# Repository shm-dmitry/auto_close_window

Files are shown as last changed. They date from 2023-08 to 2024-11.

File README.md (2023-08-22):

This project allows auto-open and auto-close your windows.
Project consists schematics of 3 modules and firmware for 2 controllers

Project re-started

In-door modules:
==============

1. Placed on window neare handle. It controls handle state (via hall sensor and magnet) and allows to you to push button open or close manually
Also this module connected to WIFI and allows to to control your window from any smart house server (via MQTT protocol).
2. Placed on up-side window frame. Contains servo, receives commands from module#1 and executes it.

Out-door module:
==============

1. Listen for a noise and check air quality. 

Project status
==============

| Hardware | status |
| ---- | ---- |
| Indoor schema :: near-handle module | no |
| Indoor schema :: servo module | no |
| Indoor schema :: digital channel to outdoor schema | no |
| Outdoor module schema :: microcontroller and its periphery | no |
| Outdoor module schema :: sensors | no |

| Board | status |
| ---- | ---- |
| Indoor board :: near-handle module | no |
| Indoor board :: servo module | no |
| Outdoor module board | no |

| Firmware | status |
| ---- | ---- |
| Indoor firmware :: hardware sensors - hall, switch and soft lock | no |
| Indoor firmware :: buttons | no |
| Indoor firmware :: servo control and calibration | no |
| Indoor firmware :: led indication | no |
| Indoor firmware :: controller | no |
| Outdoor firmware :: BMP280 | no |
| Outdoor firmware :: SGP30 | no |
| Outdoor firmware :: Noise sensor | no |
| Outdoor firmware :: Sensor value filters and controller | no |
| Outdoor firmware :: Data transmitter | no |

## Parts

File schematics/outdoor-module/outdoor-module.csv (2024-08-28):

Source: | /opt/work-iot/auto_close_window/schematics/outdoor-module/outdoor-module.kicad_sch
Date: | 2024-08-24T21:54:59+0300
Tool: | Eeschema 8.0.4-8.0.4-0~ubuntu22.04.1
Generator: | /usr/share/kicad/plugins/bom_csv_grouped_by_value_with_fp.py
Component Count: | 124
Ref | Qnty | Value | Cmp name | Footprint | Description | Vendor | DNP
C1, C2, C4, C9, C11, C16, C17, C24, C25, C27, C28, C29, C31, C33, C37, C38, C39, C40, C41, C42, C45 | 21 | 100 nF | C | Capacitor_SMD:C_0603_1608Metric | Unpolarized capacitor
C3, C7 | 2 | 100 uF | C_Polarized | Capacitor_THT:CP_Radial_D6.3mm_P2.50mm | Polarized capacitor
C5, C6 | 2 | 15 pF | C | Capacitor_SMD:C_0603_1608Metric | Unpolarized capacitor
C8, C13, C14, C20, C34, C35, C44 | 7 | 22 uF | C | Capacitor_SMD:C_1210_3225Metric | Unpolarized capacitor
C10, C15, C18, C19, C30 | 5 | 1 uF | C | Capacitor_SMD:C_0603_1608Metric | Unpolarized capacitor
C12, C26 | 2 | 2.2 uF | C | Capacitor_SMD:C_0603_1608Metric | Unpolarized capacitor
C21 | 1 | 1 nF | C | Capacitor_SMD:C_0603_1608Metric | Unpolarized capacitor
C22, C32 | 2 | 47 nF | C | Capacitor_SMD:C_0603_1608Metric | Unpolarized capacitor
C23 | 1 | 200 pF | C | Capacitor_SMD:C_0603_1608Metric | Unpolarized capacitor
C36 | 1 | 4.7 uF | C | Capacitor_SMD:C_0603_1608Metric | Unpolarized capacitor
D1 | 1 | red/green, common cathode, F3 | LED_Dual_AKA | LED_THT:LED_D5.0mm-3 | Dual LED, common cathode on pin 2
D3, D5 | 2 | 15MQ030NPBF | D | Diode_SMD:D_SMA | Diode
D4 | 1 | BAV21WS | D | Diode_SMD:D_SOD-323F | Diode
D6 | 1 | SMAJ26A | SMAJ26A | Diode_SMD:D_SMA | 400W unidirectional Transient Voltage Suppressor, 26.0Vr, SMA(DO-214AC)
D7 | 1 | ES2J | D | Diode_SMD:D_SMB | Diode
F1, F2 | 2 | 3A | Fuse | Library:FuseHolder1808 | Fuse
H1, H2, H3, H4, H5 | 5 | MountingHole | MountingHole | MountingHole:MountingHole_2.2mm_M2 | Mounting Hole without connection
J1 | 1 | 2*LiFePo4@18650@1800mAh, 6,4V | Conn_01x02_Socket | Connector_PinSocket_2.54mm:PinSocket_1x02_P2.54mm_Vertical | Generic connector, single row, 01x02, script generated
J2 | 1 | USBASP | Conn_02x05_Odd_Even | Connector_PinHeader_2.54mm:PinHeader_2x05_P2.54mm_Vertical | Generic connector, double row, 02x05, odd/even pin numbering scheme (row 1 odd numbers, row 2 even numbers), script generated (kicad-library-utils/schlib/autogen/connector/)
J3 | 1 | Charger | Conn_01x02_Socket | Connector_JST:JST_XH_B2B-XH-A_1x02_P2.50mm_Vertical | Generic connector, single row, 01x02, script generated
L3 | 1 | AMPLF0630, 8,2uH | L | Inductor_SMD:L_Abracon_ASPI-0630LR | Inductor
MK1 | 1 | VSM3729AT-GL9-A30 | MEMS-4PIN | Library:SMD03722C4
Q1, Q2 | 2 | IRLML5203 | IRLML5203 | Package_TO_SOT_SMD:SOT-23 | -3.0A Id, -30V Vds, 98mOhm Rds, P-Channel HEXFET Power MOSFET, SOT-23
Q3, Q4, Q5, Q6, Q7 | 5 | IRLML0030 | IRLML0030 | Package_TO_SOT_SMD:SOT-23 | 5.3A Id, 30V Vds, 27mOhm Rds, N-Channel HEXFET Power MOSFET, SOT-23
R1, R2, R6, R19 | 4 | 10K | R | Resistor_SMD:R_0805_2012Metric | Resistor
R3, R5, R10, R11 | 4 | 4K7 | R | Resistor_SMD:R_0805_2012Metric | Resistor
R4 | 1 | 1K | R | Resistor_SMD:R_0805_2012Metric | Resistor
R7 | 1 | 2 | R | Resistor_SMD:R_0805_2012Metric | Resistor
R8, R23, R25, R26 | 4 | 100K | R | Resistor_SMD:R_0805_2012Metric | Resistor
R9 | 1 | 45K | R | Resistor_SMD:R_0805_2012Metric | Resistor
R12 | 1 | 4R7 | R | Resistor_SMD:R_0805_2012Metric | Resistor
R13, R14, R17 | 3 | 4K | R | Resistor_SMD:R_0805_2012Metric | Resistor
R15 | 1 | 200K | R | Resistor_SMD:R_0805_2012Metric | Resistor
R16, R27 | 2 | 0.01 R | R | Resistor_SMD:R_1206_3216Metric | Resistor
R18, R21, R24, R28, R29, R30 | 6 | 10 | R | Resistor_SMD:R_0805_2012Metric | Resistor
R20 | 1 | 2K2 | R | Resistor_SMD:R_0805_2012Metric | Resistor
RV1, RV3 | 2 | RM065, 100K | R_Potentiometer | Potentiometer_THT:Potentiometer_Runtron_RM-065_Vertical | Potentiometer
RV2 | 1 | JVR-05N180M | Varistor | Varistor:RV_Disc_D7mm_W4.5mm_P5mm | Voltage dependent resistor
TP1 | 1 | CHG SUPPLY | TestPoint | TestPoint:TestPoint_Pad_D1.0mm | test point
TP2 | 1 | GND | TestPoint | Library:TestPoint_Plated_Hole_D1.0mm | test point
TP3 | 1 | 1V8 | TestPoint | TestPoint:TestPoint_Pad_D1.0mm | test point
TP4 | 1 | +5V | TestPoint | TestPoint:TestPoint_Pad_D1.0mm | test point
TP5 | 1 | 3V3 | TestPoint | TestPoint:TestPoint_Pad_D1.0mm | test point
TP6 | 1 | VSYS | TestPoint | TestPoint:TestPoint_Pad_D1.0mm | test point
TP7 | 1 | MK_OUT | TestPoint | TestPoint:TestPoint_Pad_D1.0mm | test point
TP9 | 1 | ACDET | TestPoint | TestPoint:TestPoint_Pad_D1.0mm | test point
TP10 | 1 | NOISE | TestPoint | TestPoint:TestPoint_Pad_D1.0mm | test point
TP11 | 1 | ACDRV | TestPoint | TestPoint:TestPoint_Pad_D1.0mm | test point
TP12 | 1 | ACOK | TestPoint | TestPoint:TestPoint_Pad_D1.0mm | test point
U1 | 1 | ATmega328-A | ATmega328-A | Package_QFP:TQFP-32_7x7mm_P0.8mm | 20MHz, 32kB Flash, 2kB SRAM, 1kB EEPROM, TQFP-32
U2 | 1 | STX882@315MHz | STX882 | Library:STX882_Vertical
U3 | 1 | MCP1703T-5002E | AMS1117-3.3 | Package_TO_SOT_SMD:SOT-23 | 1A Low Dropout regulator, positive, 3.3V fixed output, SOT-223
U4 | 1 | MCP1703T-3302E | AMS1117-3.3 | Package_TO_SOT_SMD:SOT-23 | 1A Low Dropout regulator, positive, 3.3V fixed output, SOT-223
U5 | 1 | MCP1703T-1802E | MCP1703Ax-500xxTT | Package_TO_SOT_SMD:SOT-23 | Low Quiescent Current LDO Regulator, 5.0V, 250mA, Vin<=16V, SOT-23
U6 | 1 | PCA9306 | PCA9306 | Package_SO:MSOP-8_3x3mm_P0.65mm | Dual bidirectional I2C Bus and SMBus voltage level translator
U7 | 1 | BME280 | BME280 | Package_LGA:Bosch_LGA-8_2.5x2.5mm_P0.65mm_ClockwisePinNumbering | 3-in-1 sensor, humidity, pressure, temperature, I2C and SPI interface, 1.71-3.6V, LGA-8
U8 | 1 | BQ24780S | BQ24780S | Package_DFN_QFN:QFN-28-1EP_4x4mm_P0.4mm_EP2.6x2.6mm_ThermalVias
U9, U10 | 2 | AD8541 | AD8211 | Package_TO_SOT_SMD:SOT-23-5 | 65V High Voltage, Current Shunt Monitor, 20V/V gain, bandwidth 500kHz, Vcc=5V, SOT-23-5
U12 | 1 | INA219 | INA219 | Package_SO:SOIC-8_3.9x4.9mm_P1.27mm
X1 | 1 | HC-49U, 8MHz | Crystal | Crystal:Crystal_HC49-U_Vertical | Two pin crystal

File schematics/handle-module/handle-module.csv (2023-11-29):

Source: | /opt/work-iot/auto_close_window/schematics/handle-module/handle-module.kicad_sch
Date: | Пн 27 ноя 2023 12:29:32
Tool: | Eeschema 7.0.9-7.0.9~ubuntu22.04.1
Generator: | /usr/share/kicad/plugins/bom_csv_grouped_by_value_with_fp.py
Component Count: | 117
Ref | Qnty | Value | Cmp name | Footprint | Description | Vendor | DNP
C1, C2, C10, C22 | 4 | 2.2 uF | C | Capacitor_SMD:C_0603_1608Metric | Unpolarized capacitor
C3, C4, C29 | 3 | 10 nF | C | Capacitor_SMD:C_0603_1608Metric | Unpolarized capacitor
C5, C6 | 2 | 100 uF | C_Polarized | Capacitor_THT:CP_Radial_D6.3mm_P2.50mm | Polarized capacitor
C7, C13, C14, C19, C30, C31, C36 | 7 | 22 uF | C | Capacitor_SMD:C_1210_3225Metric | Unpolarized capacitor
C8, C18, C27 | 3 | 1 uF | C | Capacitor_SMD:C_0603_1608Metric | Unpolarized capacitor
C9, C11, C15, C16, C20, C21, C23, C24, C32, C34, C35 | 11 | 100 nF | C | Capacitor_SMD:C_0603_1608Metric | Unpolarized capacitor
C12 | 1 | 1 nF | C | Capacitor_SMD:C_0603_1608Metric | Unpolarized capacitor
C17, C28 | 2 | 47 nF | C | Capacitor_SMD:C_0603_1608Metric | Unpolarized capacitor
C25, C26 | 2 | 15 pF | C | Capacitor_SMD:C_0603_1608Metric | Unpolarized capacitor
C33 | 1 | 10 uF | C | Capacitor_SMD:C_0603_1608Metric | Unpolarized capacitor
D1 | 1 | red/green, common cathode, F3 | LED_Dual_AKA | LED_THT:LED_D5.0mm-3 | Dual LED, common cathode on pin 2
D2, D7, D8 | 3 | 15MQ030NPBF | D | Diode_SMD:D_SMA | Diode
D3, D4, D5, D6 | 4 | BAV21WS | D | Diode_SMD:D_SOD-323F | Diode
D9, D10 | 2 | ES2J | D | Diode_SMD:D_SMB | Diode
F1, F2 | 2 | 3A | Fuse | Library:FuseHolder1808 | Fuse
H1, H2, H3, H4 | 4 | MountingHole | MountingHole | MountingHole:MountingHole_2.2mm_M2 | Mounting Hole without connection
J1 | 1 | 2*LiFePo4@18650@1800mAh, 6,4V | Conn_01x02_Socket | Connector_PinSocket_2.54mm:PinSocket_1x02_P2.54mm_Vertical | Generic connector, single row, 01x02, script generated
J2 | 1 | JST XH B3B | Conn_01x03_Pin |  | Generic connector, single row, 01x03, script generated
J3 | 1 | JST XH B3B | Conn_01x03_Socket | Connector_JST:JST_XH_B3B-XH-A_1x03_P2.50mm_Vertical | Generic connector, single row, 01x03, script generated
J4 | 1 | USBASP | Conn_02x05_Odd_Even | Connector_PinHeader_2.54mm:PinHeader_2x05_P2.54mm_Vertical | Generic connector, double row, 02x05, odd/even pin numbering scheme (row 1 odd numbers, row 2 even numbers), script generated (kicad-library-utils/schlib/autogen/connector/)
JP1 | 1 | AC Detect | SolderJumper_2_Open | Jumper:SolderJumper-2_P1.3mm_Open_TrianglePad1.0x1.5mm | Solder Jumper, 2-pole, open
L1, L2 | 2 | ? | L |  | Inductor
L3 | 1 | AMPLF0630, 8,2uH | L | Inductor_SMD:L_Abracon_ASPI-0630LR | Inductor
Q1, Q2 | 2 | IRLML5203 | IRLML5203 | Package_TO_SOT_SMD:SOT-23 | -3.0A Id, -30V Vds, 98mOhm Rds, P-Channel HEXFET Power MOSFET, SOT-23
Q3, Q4, Q5, Q6, Q7, Q8, Q9, Q10 | 8 | IRLML0030 | IRLML0030 | Package_TO_SOT_SMD:SOT-23 | 5.3A Id, 30V Vds, 27mOhm Rds, N-Channel HEXFET Power MOSFET, SOT-23
R1, R2, R3, R4, R6, R7, R16, R18, R21, R22, R25, R26 | 12 | 10K | R | Resistor_SMD:R_0805_2012Metric | Resistor
R5 | 1 | 1K | R | Resistor_SMD:R_0805_2012Metric | Resistor
R8 | 1 | 2R | R | Resistor_SMD:R_0805_2012Metric | Resistor
R9, R11, R12, R30 | 4 | 100K | R | Resistor_SMD:R_0805_2012Metric | Resistor
R10 | 1 | 45K | R | Resistor_SMD:R_0805_2012Metric | Resistor
R13 | 1 | 4R7 | R | Resistor_SMD:R_0805_2012Metric | Resistor
R14, R15, R19 | 3 | 4K | R | Resistor_SMD:R_0805_2012Metric | Resistor
R17, R28 | 2 | 0.01 R | R | Resistor_SMD:R_1206_3216Metric | Resistor
R20, R23, R27, R29 | 4 | 10 | R | Resistor_SMD:R_0805_2012Metric | Resistor
R24 | 1 | 6R8 | R | Resistor_SMD:R_0805_2012Metric | Resistor
R31 | 1 | 7K | R | Resistor_SMD:R_0805_2012Metric | Resistor
RV1 | 1 | JVR-05N180M | Varistor | Varistor:RV_Disc_D7mm_W4.5mm_P5mm | Voltage dependent resistor
SW1, SW2 | 2 | KLS7-TS3601-5.0-180 | SW_Push | Library:SW_PUSH_P6.5_W3.5 | Push button switch, generic, two pins
TP1 | 1 | VBAT | TestPoint | TestPoint:TestPoint_Pad_D1.0mm | test point
TP2 | 1 | GND | TestPoint | TestPoint:TestPoint_Plated_Hole_D2.0mm | test point
TP3 | 1 | +5V | TestPoint | TestPoint:TestPoint_Pad_D1.0mm | test point
TP4 | 1 | VSYS | TestPoint | TestPoint:TestPoint_Pad_D1.0mm | test point
TP5 | 1 | CHG SUPPLY | TestPoint | TestPoint:TestPoint_Pad_D1.0mm | test point
TP6 | 1 | ILIM | TestPoint | TestPoint:TestPoint_Pad_D1.0mm | test point
U1 | 1 | STX882@443MHz | STX882 | Library:STX882_Vertical
U2 | 1 | SRX882@443MHz | SRX882 | Library:SRX882_Vertical
U3 | 1 | AMS1117-5.0 | AMS1117-5.0 | Package_TO_SOT_SMD:SOT-223-3_TabPin2 | 1A Low Dropout regulator, positive, 5.0V fixed output, SOT-223
U4 | 1 | MCP1703T-3302E | AMS1117-3.3 | Package_TO_SOT_SMD:SOT-23 | 1A Low Dropout regulator, positive, 3.3V fixed output, SOT-223
U5 | 1 | ATmega328-A | ATmega328-A | Package_QFP:TQFP-32_7x7mm_P0.8mm | 20MHz, 32kB Flash, 2kB SRAM, 1kB EEPROM, TQFP-32
U6 | 1 | BQ24780S | BQ24780S | Package_DFN_QFN:QFN-28-1EP_4x4mm_P0.4mm_EP2.6x2.6mm_ThermalVias
X1 | 1 | HC-49U, 8MHz | Crystal | Crystal:Crystal_HC49-U_Vertical | Two pin crystal

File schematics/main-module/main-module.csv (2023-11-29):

Source: | /opt/work-iot/auto_close_window/schematics/main-module/main-module.kicad_sch
Date: | Пн 27 ноя 2023 12:27:09
Tool: | Eeschema 7.0.9-7.0.9~ubuntu22.04.1
Generator: | /usr/share/kicad/plugins/bom_csv_grouped_by_value_with_fp.py
Component Count: | 102
Ref | Qnty | Value | Cmp name | Footprint | Description | Vendor | DNP
C1 | 1 | 2.2 uF | C | Capacitor_SMD:C_0603_1608Metric | Unpolarized capacitor
C2, C9, C10, C11, C12, C19, C27, C28, C30, C32 | 10 | 22 uF | C | Capacitor_SMD:C_1210_3225Metric | Unpolarized capacitor
C3, C5, C6, C21, C33 | 5 | 10 uF | C | Capacitor_SMD:C_0603_1608Metric | Unpolarized capacitor
C4 | 1 | 1000 uF | C_Polarized | Capacitor_THT:CP_Radial_D8.0mm_P3.50mm | Polarized capacitor
C14, C15, C20, C22, C24, C34, C35 | 7 | 100 nF | C | Capacitor_SMD:C_0603_1608Metric | Unpolarized capacitor
C16 | 1 | 1 uF | C | Capacitor_SMD:C_0603_1608Metric | Unpolarized capacitor
C17, C18 | 2 | 100 uF | C_Polarized | Capacitor_THT:CP_Radial_D6.3mm_P2.50mm | Polarized capacitor
C23 | 1 | 1 nF | C | Capacitor_SMD:C_0603_1608Metric | Unpolarized capacitor
C25 | 1 | 500 nF | C | Capacitor_SMD:C_0603_1608Metric | Unpolarized capacitor
C26, C29 | 2 | 0.1 uF | C | Capacitor_SMD:C_0603_1608Metric | Unpolarized capacitor
C31 | 1 | 100 uF | C | Capacitor_SMD:C_0603_1608Metric | Unpolarized capacitor
D1 | 1 | SMAJ5.0CA-TR | ESD9B3.3ST5G | Diode_SMD:D_SMA | ESD protection diode, 3.3Vrwm, SOD-923
D2 | 1 | US1M | D | Diode_SMD:D_SMA | Diode
D4 | 1 | HER508 | D | Diode_THT:D_DO-201AD_P3.81mm_Vertical_AnodeUp | Diode
D5 | 1 | LED | LED | LED_THT:LED_D1.8mm_W3.3mm_H2.4mm | Light emitting diode
D6 | 1 | MB10S | D_Bridge_+-AA | Library:MBS | Diode bridge, +ve/-ve/AC/AC
F1 | 1 | 6A | Fuse | Library:FuseHolder1808 | Fuse
F2 | 1 | 3A | Fuse | Library:FuseHolder1808 | Fuse
H1, H2, H3, H4 | 4 | MountingHole | MountingHole | MountingHole:MountingHole_2.2mm_M2 | Mounting Hole without connection
J1 | 1 | Conn_01x02_Socket | Conn_01x02_Socket | Connector_JST:JST_XH_B2B-XH-A_1x02_P2.50mm_Vertical | Generic connector, single row, 01x02, script generated
J2 | 1 | USB_C_Receptacle_USB2.0 | USB_C_Receptacle_USB2.0 | Library:USB_C_P16_MIDMOUNT_1.6 | USB 2.0-only Type-C Receptacle connector
J3 | 1 | Charger | Conn_01x02_Socket | Connector_JST:JST_XH_B2B-XH-A_1x02_P2.50mm_Vertical | Generic connector, single row, 01x02, script generated
J4 | 1 | Power | Conn_01x02_Pin | Connector_JST:JST_XH_B2B-XH-A_1x02_P2.50mm_Vertical | Generic connector, single row, 01x02, script generated
J5 | 1 | Limit Switch | Conn_01x02_Socket | Connector_JST:JST_XH_B2B-XH-A_1x02_P2.50mm_Vertical | Generic connector, single row, 01x02, script generated
J6 | 1 | Conn_01x04_Socket | Conn_01x04_Socket | Connector_JST:JST_XH_B4B-XH-A_1x04_P2.50mm_Vertical | Generic connector, single row, 01x04, script generated
J7 | 1 | Conn_01x04_Pin | Conn_01x04_Pin |  | Generic connector, single row, 01x04, script generated |  | DNP
JP1 | 1 | Charge from flusher | SolderJumper_2_Open | Jumper:SolderJumper-2_P1.3mm_Open_TrianglePad1.0x1.5mm | Solder Jumper, 2-pole, open
JP2 | 1 | FLUSH | SolderJumper_2_Open | Jumper:SolderJumper-2_P1.3mm_Open_TrianglePad1.0x1.5mm | Solder Jumper, 2-pole, open
JP3 | 1 | RESET | SolderJumper_2_Open | Jumper:SolderJumper-2_P1.3mm_Open_TrianglePad1.0x1.5mm | Solder Jumper, 2-pole, open
M1 | 1 | Creality 42-40 | Stepper_Motor_bipolar |  | 4-wire bipolar stepper motor |  | DNP
Q1, Q6 | 2 | IRLML0030 | IRLML0030 | Package_TO_SOT_SMD:SOT-23 | 5.3A Id, 30V Vds, 27mOhm Rds, N-Channel HEXFET Power MOSFET, SOT-23
Q2 | 1 | IRF7425PbF | IRF7404 | Package_SO:SOIC-8_3.9x4.9mm_P1.27mm | -6.7A Id, -20V Vds, P-Channel HEXFET Power MOSFET, SO-8
Q3, Q4 | 2 | BC847 | BC847 | Package_TO_SOT_SMD:SOT-23 | 0.1A Ic, 45V Vce, NPN Transistor, SOT-23
Q7, Q8 | 2 | IRF7832PbF | IRF7403 | Package_SO:SOIC-8_3.9x4.9mm_P1.27mm | 9.7A Id, 30V Vds, N-Channel HEXFET Power MOSFET, SO-8
R1 | 1 | 22K | R | Resistor_SMD:R_0805_2012Metric | Resistor
R2 | 1 | 44K | R | Resistor_SMD:R_0805_2012Metric | Resistor
R3, R6, R7, R9, R12, R13, R14, R18, R20, R22 | 10 | 10K | R | Resistor_SMD:R_0805_2012Metric | Resistor
R4, R5, R10, R15, R16, R17, R21 | 7 | 1K | R | Resistor_SMD:R_0805_2012Metric | Resistor
R11, R19 | 2 | 5K1 | R | Resistor_SMD:R_0805_2012Metric | Resistor
RV2 | 1 | 1K | R_Potentiometer | Potentiometer_THT:Potentiometer_Runtron_RM-065_Vertical | Potentiometer
SW1, SW2 | 2 | KLS7-TS3601-5.0-180 | SW_Push | Library:SW_PUSH_P6.5_W3.5 | Push button switch, generic, two pins
T1 | 1 | Transformer_1P_SS | Transformer_1P_SS | Connector_JST:JST_XH_B5B-XH-A_1x05_P2.50mm_Vertical | Transformer, single primary, split secondary
TP1, TP5 | 2 | GND | TestPoint | TestPoint:TestPoint_Plated_Hole_D2.0mm | test point
TP2 | 1 | +5V | TestPoint | TestPoint:TestPoint_Pad_D1.0mm | test point
TP3 | 1 | +3V3 | TestPoint | TestPoint:TestPoint_Pad_D1.0mm | test point
TP6 | 1 | VREF | TestPoint | TestPoint:TestPoint_Pad_D1.0mm | test point
U1 | 1 | CP2102N-Axx-xQFN28 | CP2102N-Axx-xQFN28 | Package_DFN_QFN:QFN-28-1EP_5x5mm_P0.5mm_EP3.35x3.35mm | USB to UART master bridge, QFN-28
U3 | 1 | AMS1117-5.0 | AMS1117-5.0 | Package_TO_SOT_SMD:SOT-223-3_TabPin2 | 1A Low Dropout regulator, positive, 5.0V fixed output, SOT-223
U4 | 1 | AMS1117-3.3 | AMS1117-3.3 | Package_TO_SOT_SMD:SOT-223-3_TabPin2 | 1A Low Dropout regulator, positive, 3.3V fixed output, SOT-223
U6 | 1 | SRX882@433Mhz | SRX882 | Library:SRX882_Vertical
U7 | 1 | STX882@433Mhz | STX882 | Library:STX882_Vertical
U8 | 1 | ESP32-WROOM-32 | ESP32-WROOM-32 | RF_Module:ESP32-WROOM-32 | RF Module, ESP32-D0WDQ6 SoC, Wi-Fi 802.11b/g/n, Bluetooth, BLE, 32-bit, 2.7-3.6V, onboard antenna, SMD
U9 | 1 | TL494 | TL494 | Package_SO:SO-16_3.9x9.9mm_P1.27mm | Pulse-Width-Modulation Control Circuits, PDIP-16/SOIC-16/TSSOP-16
U10 | 1 | SRX882@315Mhz | SRX882 | Library:SRX882_Vertical
U11, U12 | 2 | FAN3100 | FAN3100 | Package_TO_SOT_SMD:SOT-23-5
U13 | 1 | TMC2209_Module | TMC2209_Module | Library:TMC2209 | https://3dtoday.ru/upload/posts/main/jvm2GKLWPIfGRwuSMjZmxTKwaNKRceVa6pa1KJ9i.jpeg

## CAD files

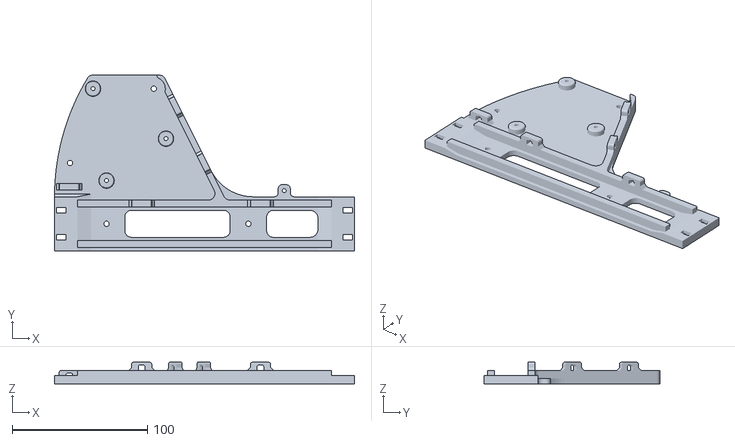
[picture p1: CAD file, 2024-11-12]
3d/mechanics-v2-servo_plateplate-v2.stl
222.0 x 130.0 x 16.0

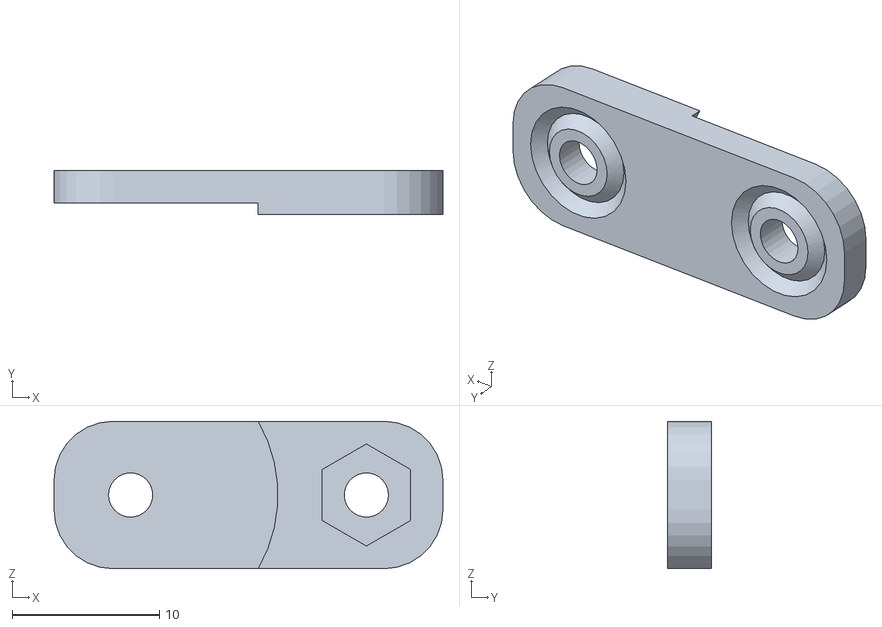
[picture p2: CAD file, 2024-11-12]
3d/mechanics-v2-window-clampwindow-clamp-3-2.stl
26.4 x 3.00 x 10.0

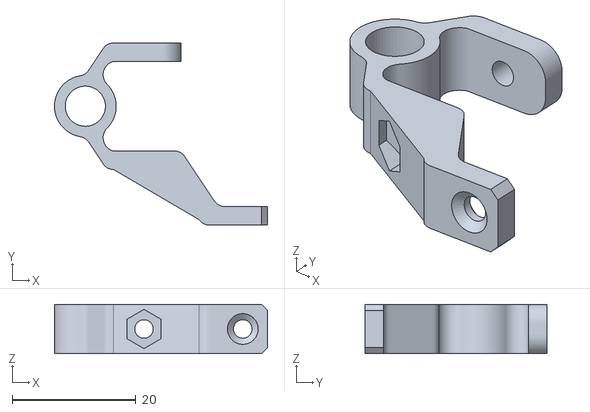
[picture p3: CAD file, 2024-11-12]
3d/mechanics-v2-window-clampwindow-clamp-5.stl
34.5 x 29.5 x 8.00

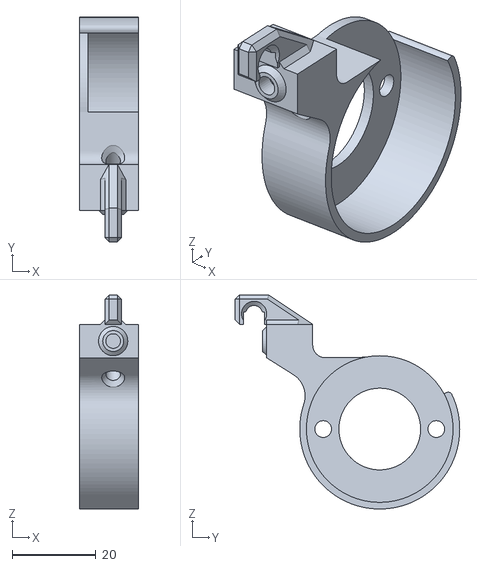
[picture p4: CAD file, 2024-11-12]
3d/mechanics-v2-rubberrubber-bearing-holder.stl
14.0 x 53.6 x 51.1

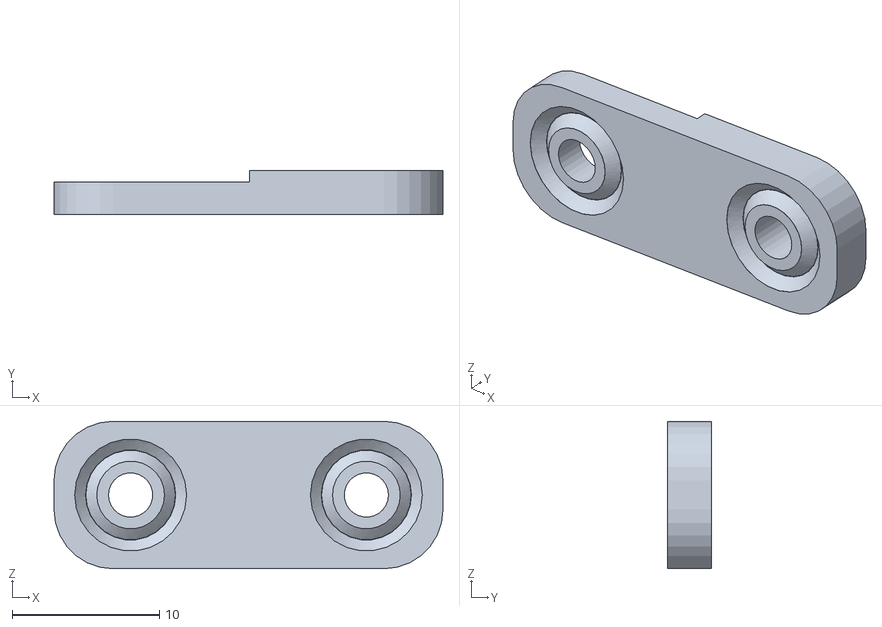
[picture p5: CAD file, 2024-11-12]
3d/mechanics-v2-window-clampwindow-clamp-3-1.stl
26.4 x 3.00 x 10.0

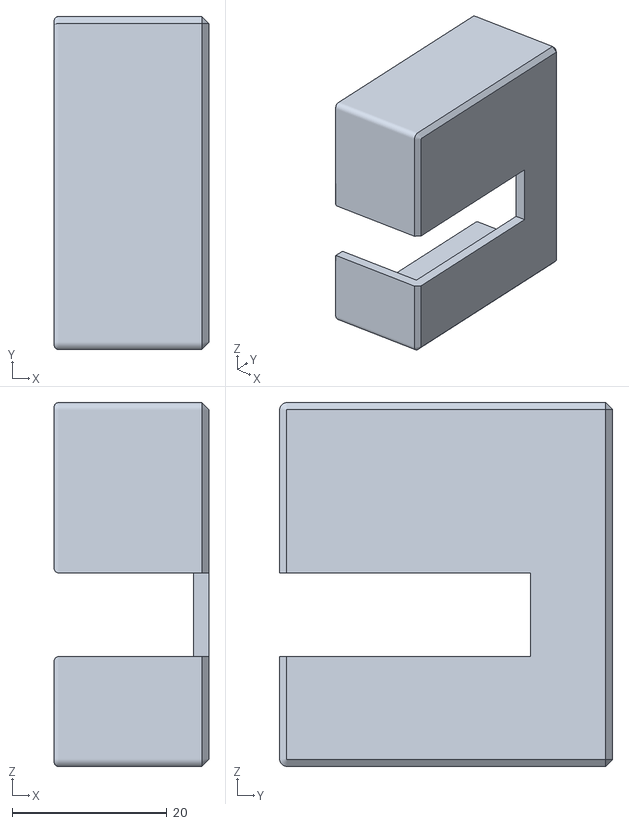
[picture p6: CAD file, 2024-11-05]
3d/mechanics-v2-servo_platecolor-cup.stl
20.0 x 43.0 x 47.0

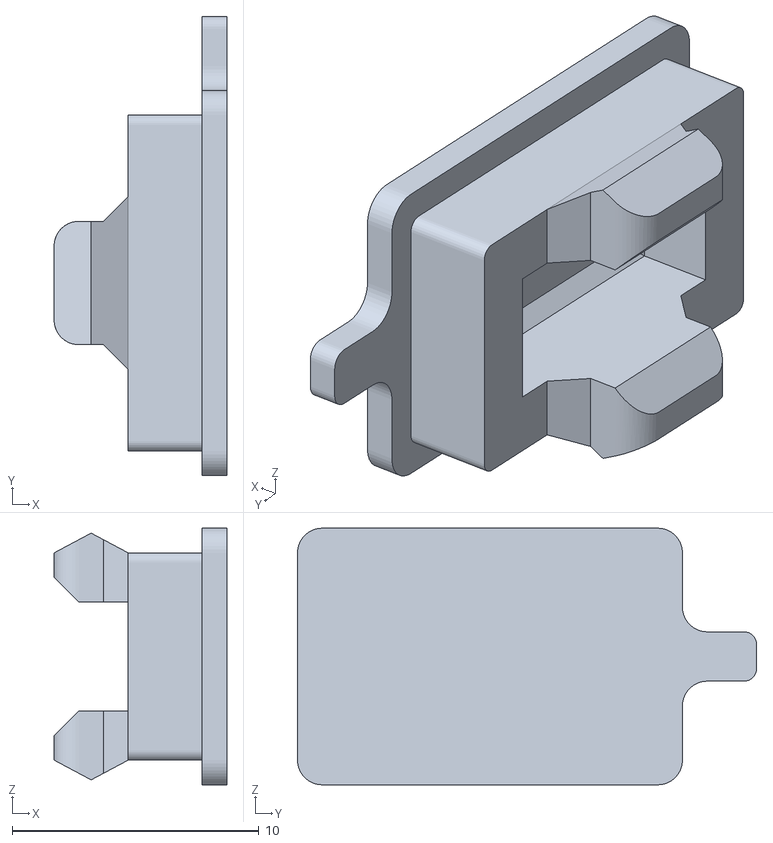
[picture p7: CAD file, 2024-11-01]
3d/mechanics-v2-mmmm-usb-cup.stl
7.00 x 18.6 x 10.4

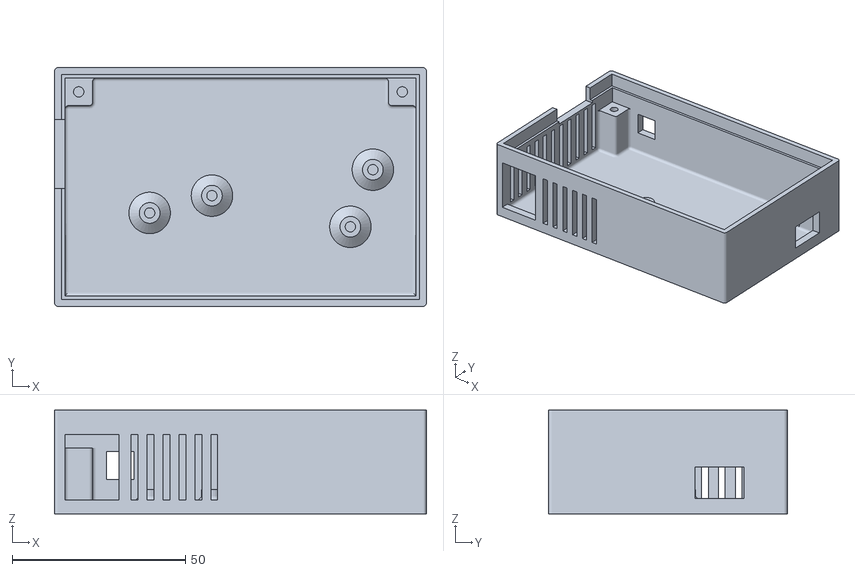
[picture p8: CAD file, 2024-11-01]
3d/mechanics-v2-mmmm-box-down.stl
107.5 x 69.0 x 30.0

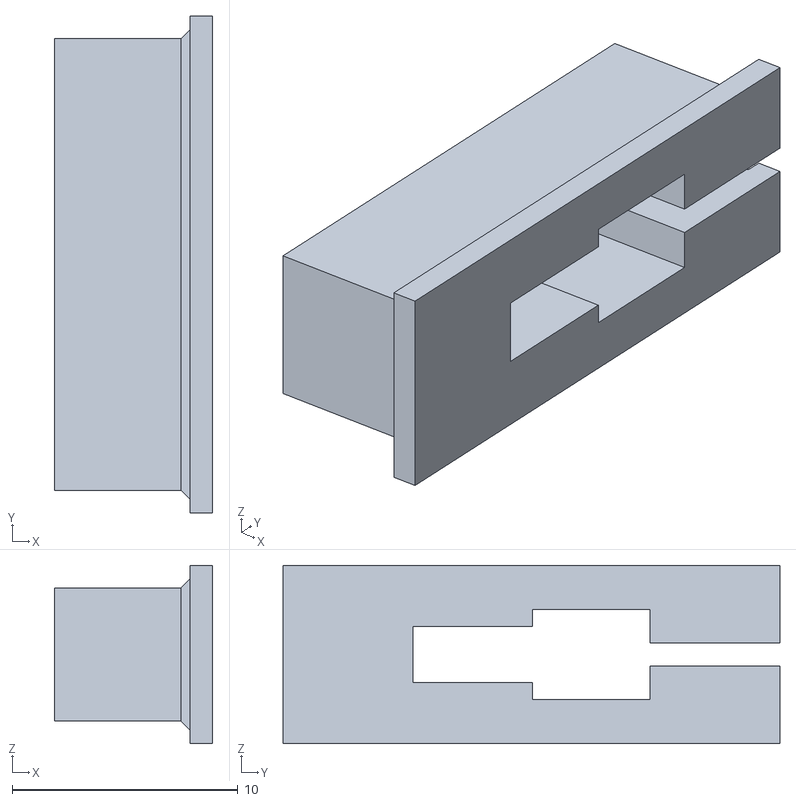
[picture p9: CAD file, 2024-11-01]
3d/mechanics-v2-mmmm-cabel-clamp.stl
7.00 x 22.0 x 7.90

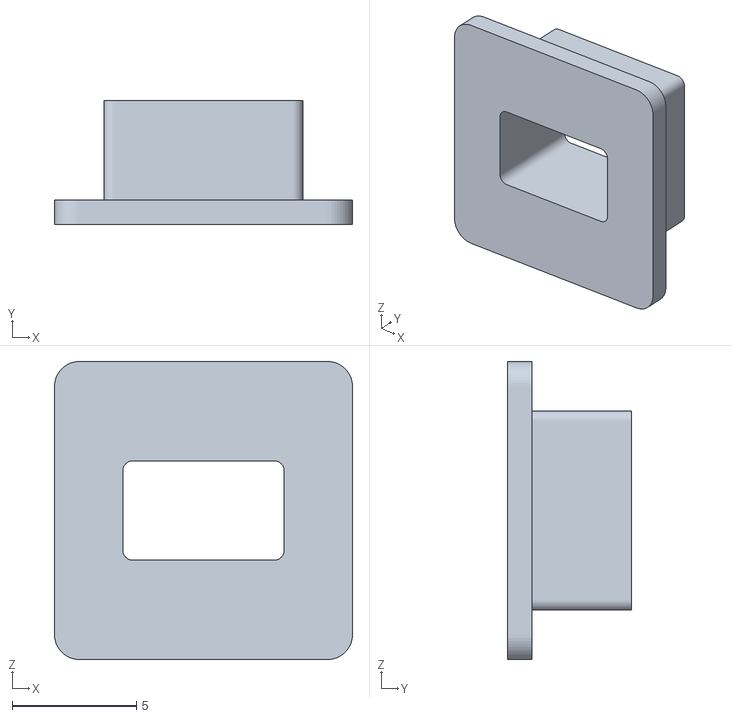
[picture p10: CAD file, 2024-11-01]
3d/mechanics-v2-mmmm-supply-clamp.stl
12.0 x 5.00 x 12.0

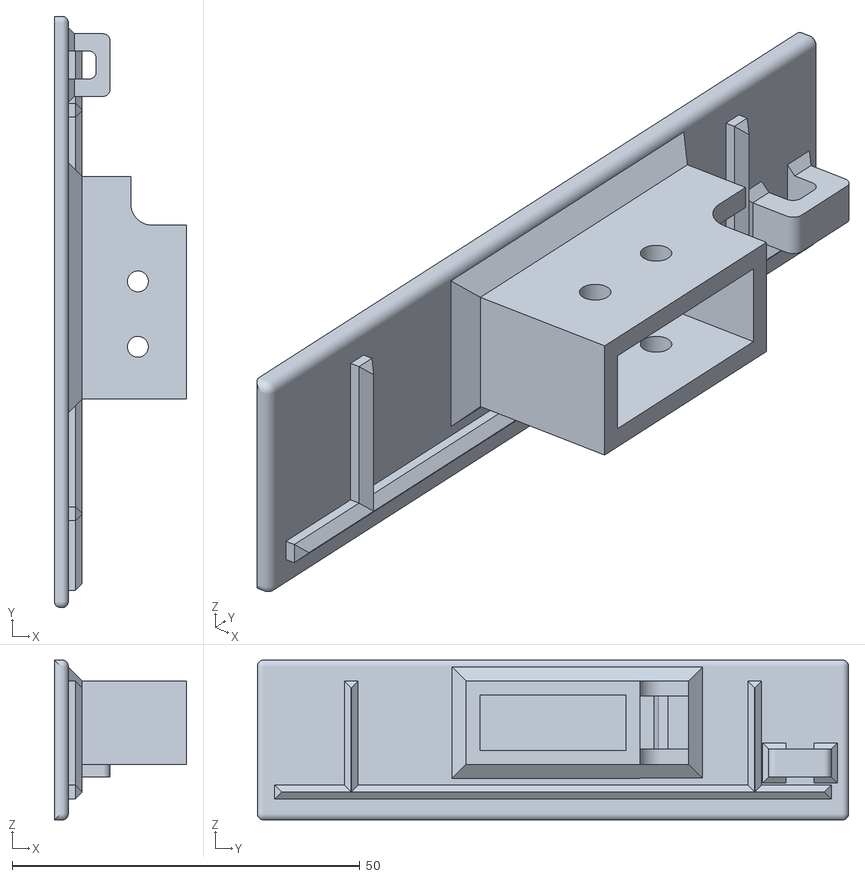
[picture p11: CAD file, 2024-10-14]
3d/mechanics-v2-window-clampwindow-limit-sw-holder.stl
19.0 x 85.0 x 23.0

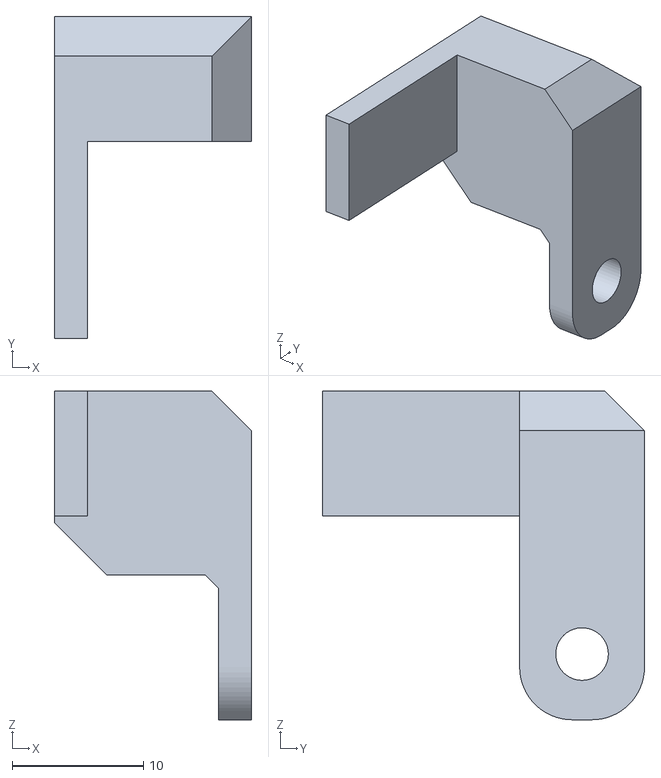
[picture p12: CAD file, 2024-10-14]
3d/mechanics-v2-window-clampwindow-clamp-1-r-sw-hand-left.stl
15.0 x 24.5 x 25.0

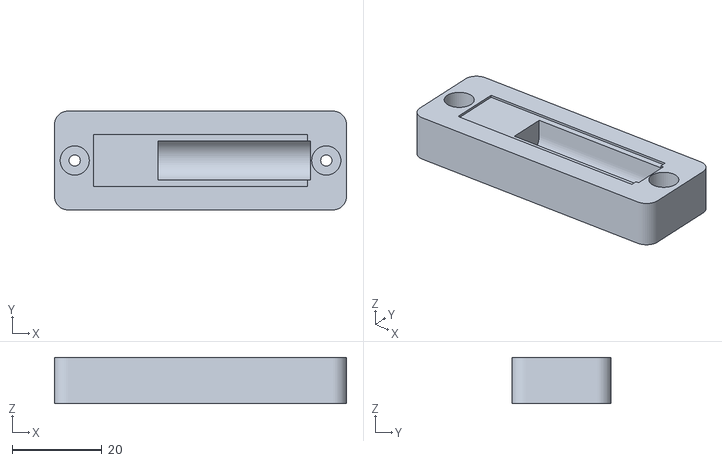
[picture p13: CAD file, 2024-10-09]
3d/mechanics-v2-pdu2pdu2-box-down.stl
65.0 x 22.0 x 10.3

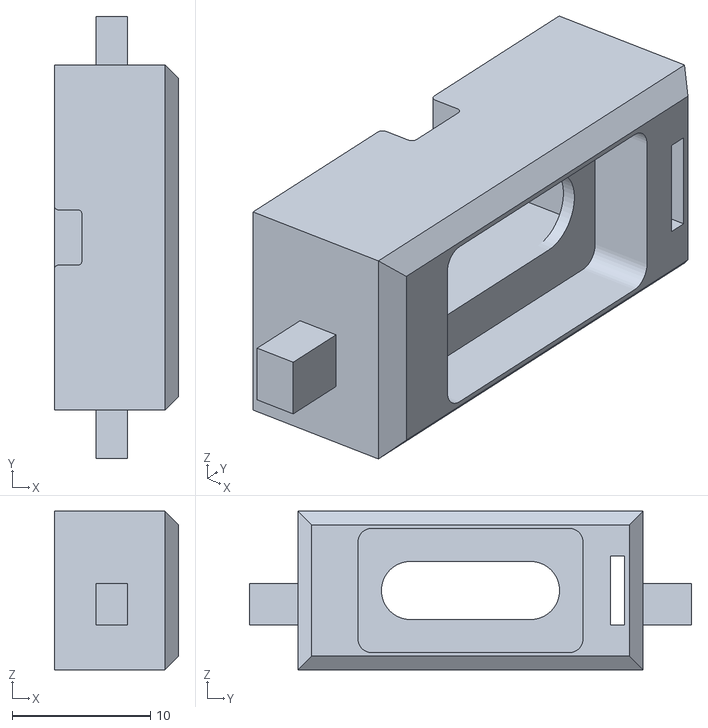
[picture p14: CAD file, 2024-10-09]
3d/mechanics-v2-hmhm-charger-port.stl
9.00 x 32.0 x 11.5

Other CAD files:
3d/mechanics-v2-window-clampwindow-clamp-4.stl
3d/mechanics-v2-pdu2pdu-box-up.stl
3d/mechanics-v2-mmmm-charge-button.stl
3d/mechanics-v2-servo_platesw420-adapter.stl
3d/mechanics-v2-hmhm-button.stl
3d/mechanics-v2-hmhm-charger-port-cup.stl
3d/mechanics-v2-hmhm-down.stl
3d/mechanics-v2-hmhm-glass.stl
3d/mechanics-v2-hmhm-up.stl
3d/mechanics-v2-mmmm-box-up.stl
3d/mechanics-v2-mmmm-charger-cup.stl
3d/mechanics-v2-mmmm-charger-port.stl
3d/mechanics-v2-rubberrubber-tensioner.stl
3d/mechanics-v2-servo_platedebug-wall-support.stl
3d/mechanics-v2-servo_platemicrophone-air-ring.stl
3d/mechanics-v2-servo_plateservo-holder-cabel.stl
3d/mechanics-v2-servo_plateservo-holder-v2.stl
3d/mechanics-v2-servolimit-switch-cabel-holder.stl
3d/mechanics-v2-servolimit-switch-extboard-holder.stl
3d/mechanics-v2-servolimiters.stl
3d/mechanics-v2-servoservo-hand.stl
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

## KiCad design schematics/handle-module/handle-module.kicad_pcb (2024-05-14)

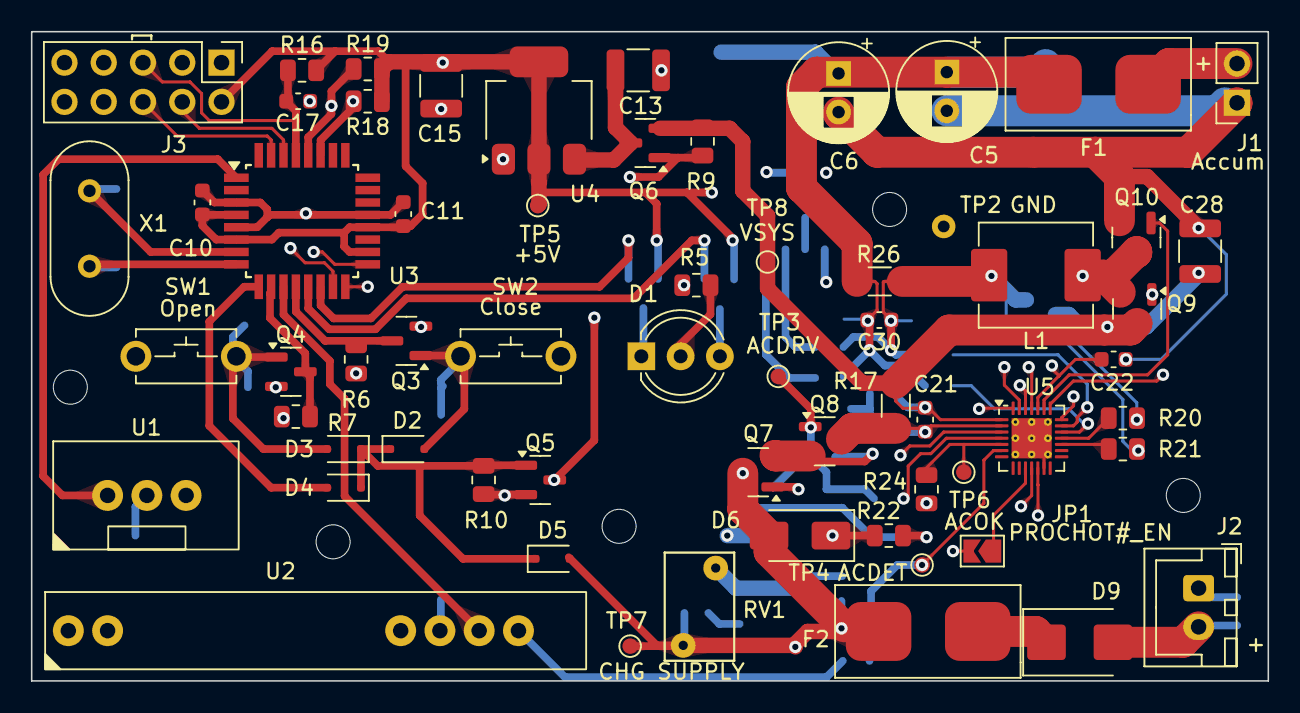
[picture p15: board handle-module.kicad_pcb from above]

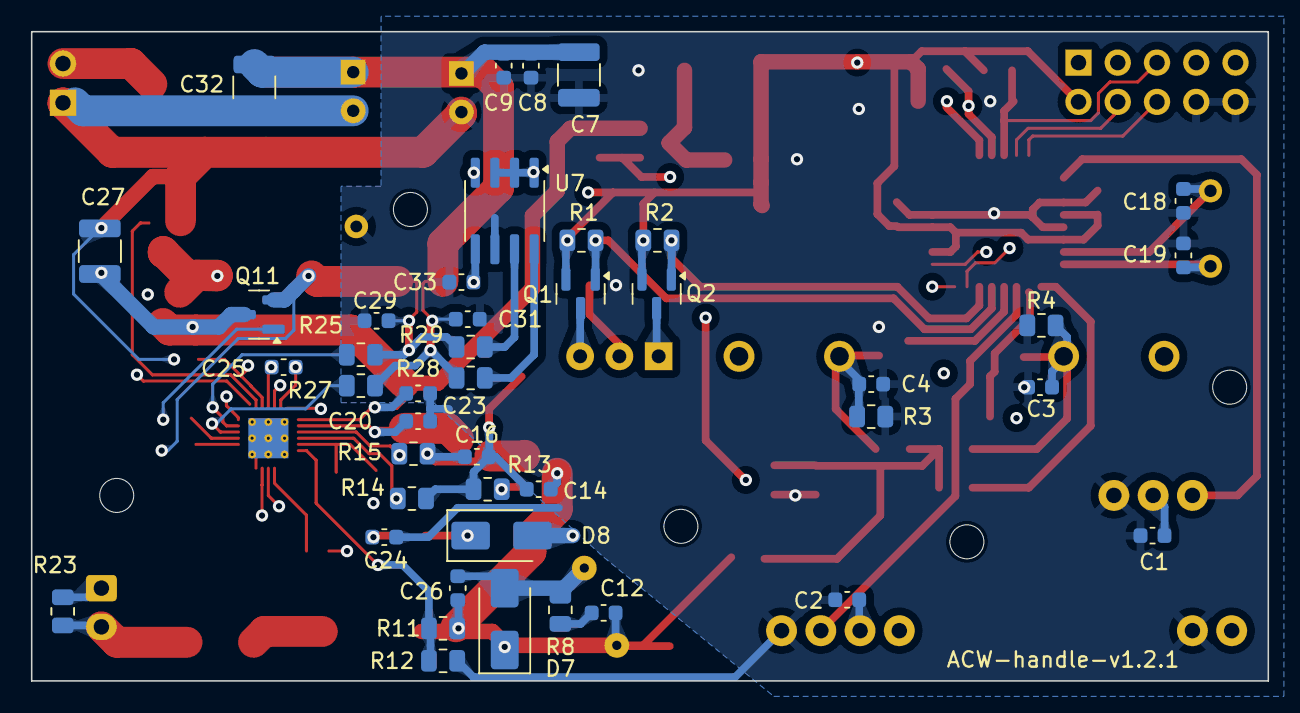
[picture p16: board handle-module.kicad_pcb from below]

Board: 4 copper layers, 80.0 x 42.0 mm, 114 parts (43 on the bottom side), 61 nets.

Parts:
C1, C2, C8, C12, C22, C24: 2.2 uF; C_0603_1608Metric
C3, C4, C9, C10, C11, C17, C20, C21, C23, C29, C30, C31, C33: 100 nF; C_0603_1608Metric
C5, C6: 100 uF; CP_Radial_D6.3mm_P2.50mm
C7, C13, C15, C27, C28, C32: 22 uF; C_1210_3225Metric
C14: 1 nF; C_0603_1608Metric
C16, C25: 47 nF; C_0603_1608Metric
C18, C19: 15 pF; C_0603_1608Metric
C26: 4.7 uF; C_0603_1608Metric
D1: red/green, common cathode, F3; LED_D5.0mm-3
D2, D3, D4, D5: BAT760; D_SOD-323F
D6, D8: 15MQ030NPBF; D_SMA
D7: SMAJ26A; D_SMA
D9: ES2J; D_SMB
F1, F2: 3A; FuseHolder1808
H1, H2, H3, H4, H5: MountingHole; MountingHole_2.2mm_M2
J1: 2*LiFePo4@18650@1800mAh, 6,4V; PinSocket_1x02_P2.54mm_Vertical
J2: Charger; JST_XH_B2B-XH-A_1x02_P2.50mm_Vertical
J3: USBASP; PinHeader_2x05_P2.54mm_Vertical
JP1: PROCHOT#_EN; SolderJumper-2_P1.3mm_Open_TrianglePad1.0x1.5mm
L1: AMPLF0630, 8,2uH; L_Abracon_ASPI-0630LR
NT1: AGND/PGND; NetTie-2_SMD_Pad2.0mm
NT2, NT3: NetTie_2; NetTie-2_SMD_Pad0.5mm
Q1, Q2, Q6: IRLML5203; SOT-23
Q3, Q4, Q5, Q7, Q8, Q9, Q10, Q11: IRLML0030; SOT-23
R1, R2, R3, R4, R6, R7, R9, R10, R16, R18, R19, R24: 10K; R_0805_2012Metric
R5: 620; R_0805_2012Metric
R8: 5R; R_0805_2012Metric
R11: 100K; R_0805_2012Metric
R12: 45K; R_0805_2012Metric
R13: 5; R_0805_2012Metric
R14, R15: 3K9; R_0805_2012Metric
R17, R26: 0.01 R; R_1206_3216Metric
R20: 3K3; R_0805_2012Metric
R21, R22, R25, R27, R28, R29: 10; R_0805_2012Metric
R23: 2K2; R_0805_2012Metric
RV1: JVR-05N180M; RV_Disc_D7mm_W4.5mm_P5mm
SW1, SW2: KLS7-TS3601-5.0-180; SW_PUSH_P6.5_W3.5
TP2: GND; TestPoint_Plated_Hole_D1.0mm
TP3: ACDRV; TestPoint_Pad_D1.0mm
TP4: ACDET; TestPoint_Pad_D1.0mm
TP5: +5V; TestPoint_Pad_D1.0mm
TP6: ACOK; TestPoint_Pad_D1.0mm
TP7: CHG SUPPLY; TestPoint_Pad_D1.0mm
TP8: VSYS; TestPoint_Pad_D1.0mm
U1: STX882@443MHz; STX882_Vertical
U2: SRX882@443MHz; SRX882_Vertical
U3: ATmega328-A; TQFP-32_7x7mm_P0.8mm
U4: AMS1117-5.0; SOT-223-3_TabPin2
U5: BQ24780S; QFN-28-1EP_4x4mm_P0.4mm_EP2.6x2.6mm_ThermalVias
U7: INA219; SOIC-8_3.9x4.9mm_P1.27mm
X1: HC-49U, 8MHz; Crystal_HC49-U_Vertical

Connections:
+5V: C1.1, C2.1, C10.1, C11.1, C15.1, C33.1, J3.2, Q1.2 (S), Q2.2 (S), R1.2, R2.2, R6.2, R7.2, R16.2, R18.1, R19.1, R24.2, TP5.1, U1.3 (VCC), U2.3 (VCC), U2.4 (CS), U3.4 (VCC), U3.6 (VCC), U3.18 (AVCC), U3.20 (AREF), U4.2 (VO), U7.5 (VCC)
/CHARGER_BATDRV: Q11.1 (G), R20.1
/CHARGER_BATSRC: C29.1, C30.1, L1.2, NT2.2, Q11.2 (S), R21.1, R26.1
/CHARGER_SRN: NT3.1, R27.1, R28.1
/CHARGER_SRP: NT2.1, R25.2, R29.2
/CHARGER_SUPPLY: C12.1, C14.1, C26.1, D5.2 (A), D6.2 (A), D7.1 (A1), F2.2, Q7.3 (D), R11.1, RV1.1, TP7.1
/CHR_VSYS_NMOS: C16.1, Q7.2 (S), Q8.2 (S), R15.1
/CLOSE_BUTTON: C4.2, D2.2 (A), Q3.1 (G), R3.1, SW2.1
/CLOSE_BUTTON_5V#: Q3.3 (D), R6.1, U3.12 (PB0)
/FM_IN: U2.5 (DATA), U3.11 (PD7)
/FM_OUT: U1.2 (DATA), U3.1 (PD3)
/IC_POWER_UP: D4.2 (A), U3.9 (PD5)
/LED_GREEN#: Q1.1 (G), R1.1, U3.13 (PB1)
/LED_RED#: Q2.1 (G), R2.1, U3.14 (PB2)
/MISO: J3.9, U3.16 (PB4)
/MOSI: J3.1, U3.15 (PB3)
/OPEN_BUTTON: C3.2, D3.2 (A), Q4.1 (G), R4.1, SW1.2
/OPEN_BUTTON_5V#: Q4.3 (D), R7.1, U3.10 (PD6)
/PROCHOT#: JP1.2 (B), Q5.3 (D), Q6.1 (G), R9.2
/RESET#: C17.1, J3.5, R16.1, U3.29 (~RESET/PC6)
/RXD: J3.4, U3.30 (PD0)
/SCK: J3.7, U3.17 (PB5)
/SCL: R19.2, U3.28 (PC5), U5.12 (SCL), U7.4 (SCL)
/SDA: R18.2, U3.27 (PC4), U5.11 (SDA), U7.1 (A1), U7.2 (A0), U7.3 (SDA)
/TXD: J3.6, U3.31 (PD1)
/VBAT: C5.1, C6.1, C7.1, C8.1, C9.2, C30.2, C31.1, C32.1, D8.2 (A), F1.2, NT3.2, R26.2, SW1.1, SW2.2
/VSYS: C21.2, C23.1, C27.1, C28.1, Q6.2 (S), Q9.3 (D), Q11.3 (D), R9.1, R17.2, TP8.1, U5.1 (ACN)
GNDA: C1.2, C2.2, C3.1, C4.1, C6.2, C7.2, C8.2, C9.1, C10.2, C11.2, C13.2, C15.2, C17.2, C18.2, C19.2, C20.2, C23.2, C24.2, C29.2, C31.2, C33.2, J3.8, J3.10, NT1.2, Q3.2 (S), Q4.2 (S), Q5.2 (S), R3.2, R4.2, R5.2, R10.2, R12.2, TP2.1, U1.4 (GND), U2.2 (GND), U2.6 (GND), U3.3 (GND), U3.5 (GND), U3.21 (GND), U4.1 (GND), U5.22 (AGND), U7.6 (GND)
GNDPWR: C5.2, C22.2, C26.2, C27.2, C28.2, C32.2, D7.2 (A2), J1.1, J2.1, NT1.1, Q10.2 (S), R8.2, R23.2, RV1.2, U5.13 (CMPIN), U5.29 (PGND)
unnamed: C12.2, R8.1
unnamed: D1.1 (A1), Q2.3 (D)
unnamed: D1.3 (A2), Q1.3 (D)
unnamed: D1.2 (K), R5.1
unnamed: D2.1 (K), D3.1 (K), D4.1 (K), D5.1 (K), Q5.1 (G), R10.1
unnamed: D6.1 (K), D8.1 (K), R22.2
unnamed: D9.2 (A), J2.2, R23.1
unnamed: D9.1 (K), F2.1
unnamed: F1.1, J1.2
unnamed: JP1.1 (A), U5.10 (PROCHOT#)
unnamed: C13.1, Q6.3 (D), U4.3 (VI)
unnamed: Q7.1 (G), R13.1
unnamed: C20.1, C21.1, Q8.3 (D), R17.1, U5.2 (ACP)
unnamed: C14.2, C16.2, Q8.1 (G), R13.2, R14.1, TP3.1
unnamed: Q9.1 (G), U5.26 (HIDRV)
unnamed: C25.2, L1.1, Q9.2 (S), Q10.3 (D), U5.27 (PHASE)
unnamed: Q10.1 (G), U5.23 (LODRV)
unnamed: C18.1, U3.7 (XTAL1/PB6), X1.2
unnamed: C19.1, U3.8 (XTAL2/PB7), X1.1
unnamed: R11.2, R12.1, TP4.1, U5.6 (ACDET)
unnamed: R14.2, U5.4 (ACDRV)
unnamed: R24.1, TP6.1, U5.5 (ACOK)
unnamed: R20.2, U5.18 (BATDRV)
unnamed: R21.2, U5.17 (BATSRC)
unnamed: C25.1, U5.25 (BTST)
unnamed: R15.2, U5.3 (CMSRC)
unnamed: C22.1, U5.21 (ILIM), U5.24 (REGN)
unnamed: R27.2, U5.19 (SRN)
unnamed: R25.1, U5.20 (SRP)
unnamed: C24.1, R22.1, U5.28 (VCC)
unnamed: R28.2, U7.8 (VIN_+)
unnamed: R29.1, U7.7 (VIN_-)

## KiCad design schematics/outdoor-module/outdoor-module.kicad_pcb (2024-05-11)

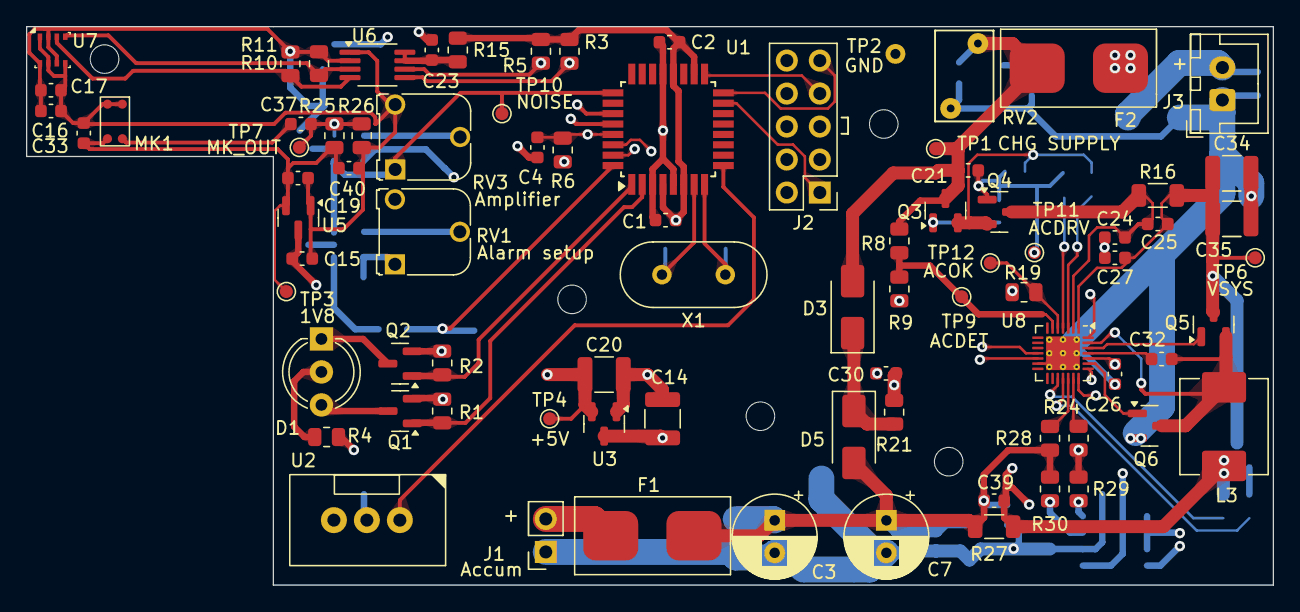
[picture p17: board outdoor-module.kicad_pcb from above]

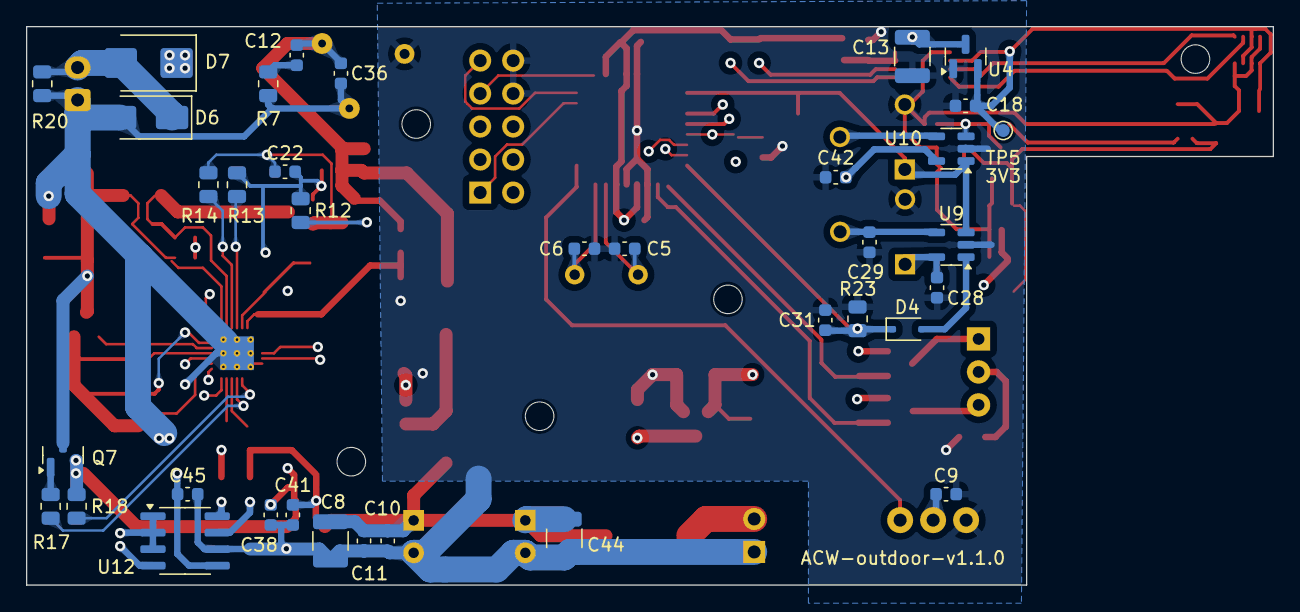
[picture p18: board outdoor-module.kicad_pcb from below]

Board: 4 copper layers, 96.0 x 43.0 mm, 127 parts (37 on the bottom side), 63 nets.

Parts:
C1, C2, C4, C9, C11, C16, C17, C24, C25, C27, C28, C29, C31, C33, C37, C38, C39, C40, C41, C42, C45: 100 nF; C_0603_1608Metric
C3, C7: 100 uF; CP_Radial_D6.3mm_P2.50mm
C5, C6: 15 pF; C_0603_1608Metric
C8, C13, C14, C20, C34, C35, C44: 22 uF; C_1210_3225Metric
C10, C15, C18, C19, C30: 1 uF; C_0603_1608Metric
C12, C26: 2.2 uF; C_0603_1608Metric
C21: 1 nF; C_0603_1608Metric
C22, C32: 47 nF; C_0603_1608Metric
C23: 200 pF; C_0603_1608Metric
C36: 4.7 uF; C_0603_1608Metric
D1: red/green, common cathode, F3; LED_D5.0mm-3
D3, D5: 15MQ030NPBF; D_SMA
D4: BAV21WS; D_SOD-323F
D6: SMAJ26A; D_SMA
D7: ES2J; D_SMB
F1, F2: 3A; FuseHolder1808
H1, H2, H3, H4, H5: MountingHole; MountingHole_2.2mm_M2
J1: 2*LiFePo4@18650@1800mAh, 6,4V; PinSocket_1x02_P2.54mm_Vertical
J2: USBASP; PinHeader_2x05_P2.54mm_Vertical
J3: Charger; JST_XH_B2B-XH-A_1x02_P2.50mm_Vertical
L3: AMPLF0630, 8,2uH; L_Abracon_ASPI-0630LR
MK1: VSM3729AT-GL9-A30; SMD03722C4
NT1: AGND/PGND; NetTie-2_SMD_Pad2.0mm
NT2, NT3: NetTie_2; NetTie-2_SMD_Pad0.5mm
Q1, Q2: IRLML5203; SOT-23
Q3, Q4, Q5, Q6, Q7: IRLML0030; SOT-23
R1, R2, R6, R19: 10K; R_0805_2012Metric
R3, R5, R10, R11: 4K7; R_0805_2012Metric
R4: 1K; R_0805_2012Metric
R7: 2; R_0805_2012Metric
R8, R23, R25, R26: 100K; R_0805_2012Metric
R9: 45K; R_0805_2012Metric
R12: 4R7; R_0805_2012Metric
R13, R14, R17: 4K; R_0805_2012Metric
R15: 200K; R_0805_2012Metric
R16, R27: 0.01 R; R_1206_3216Metric
R18, R21, R24, R28, R29, R30: 10; R_0805_2012Metric
R20: 2K2; R_0805_2012Metric
RV1, RV3: RM065, 100K; Potentiometer_Runtron_RM-065_Vertical
RV2: JVR-05N180M; RV_Disc_D7mm_W4.5mm_P5mm
TP1: CHG SUPPLY; TestPoint_Pad_D1.0mm
TP2: GND; TestPoint_Plated_Hole_D1.0mm
TP3: 1V8; TestPoint_Pad_D1.0mm
TP4: +5V; TestPoint_Pad_D1.0mm
TP5: 3V3; TestPoint_Pad_D1.0mm
TP6: VSYS; TestPoint_Pad_D1.0mm
TP7: MK_OUT; TestPoint_Pad_D1.0mm
TP9: ACDET; TestPoint_Pad_D1.0mm
TP10: NOISE; TestPoint_Pad_D1.0mm
TP11: ACDRV; TestPoint_Pad_D1.0mm
TP12: ACOK; TestPoint_Pad_D1.0mm
U1: ATmega328-A; TQFP-32_7x7mm_P0.8mm
U2: STX882@315MHz; STX882_Vertical
U3: MCP1703T-5002E; SOT-23
U4: MCP1703T-3302E; SOT-23
U5: MCP1703T-1802E; SOT-23
U6: PCA9306; MSOP-8_3x3mm_P0.65mm
U7: BME280; Bosch_LGA-8_2.5x2.5mm_P0.65mm_ClockwisePinNumbering
U8: BQ24780S; QFN-28-1EP_4x4mm_P0.4mm_EP2.6x2.6mm_ThermalVias
U9, U10: AD8541; SOT-23-5
U12: INA219; SOIC-8_3.9x4.9mm_P1.27mm
X1: HC-49U, 8MHz; Crystal_HC49-U_Vertical

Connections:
+1V8: C19.1, C33.1, C40.1, MK1.1 (VCC), R25.1, TP3.1, U5.2 (VO)
+3V3: C16.1, C17.1, C18.2, R10.1, R11.1, TP5.1, U4.2 (VO), U6.2 (VREF1), U7.2 (CSB), U7.6 (VDDIO), U7.8 (VDD)
+5V: C1.1, C2.1, C9.1, C13.1, C15.1, C20.1, C28.1, C42.1, C45.1, J2.2, Q1.2 (S), Q2.2 (S), R1.2, R2.2, R3.1, R5.1, R6.2, R15.1, R19.2, RV1.1, TP4.1, U1.4 (VCC), U1.6 (VCC), U1.18 (AVCC), U1.20 (AREF), U2.3 (VCC), U3.2 (VO), U4.3 (VI), U5.3 (VI), U9.5 (V+), U10.5 (V+), U12.5 (VCC)
/CHARGER_BATDRV: Q7.1 (G), R17.1
/CHARGER_BATSRC: C38.1, C39.1, L3.2, NT2.2, Q7.2 (S), R18.1, R27.1
/CHARGER_DONE#: Q1.1 (G), R1.1, U1.2 (PD4)
/CHARGER_IN_PROGRESS#: Q2.1 (G), R2.1, U1.1 (PD3)
/CHARGER_SRN: NT3.1, R28.1, R30.1
/CHARGER_SRP: NT2.1, R24.1, R29.2
/CHARGER_SUPPLY: C12.1, C21.1, C36.1, D3.2 (A), F2.2, Q3.3 (D), R8.1, RV2.1, TP1.1
/FM_OUT: U1.9 (PD5), U2.2 (DATA)
/MISO: J2.9, U1.16 (PB4)
/MOSI: J2.1, U1.15 (PB3)
/NOISE: RV3.1, TP10.1, U1.25 (PC2), U9.3 (Vin+), U10.1 (OUT)
/NOISE_ALARM: C31.1, D4.1 (K), R23.1, U1.32 (PD2)
/RESET#: C4.1, J2.5, R6.1, U1.29 (~RESET/PC6)
/RXD: J2.4, U1.30 (PD0)
/SCK: J2.7, U1.17 (PB5)
/SCL: R5.2, U1.28 (PC5), U6.6 (SCL2), U8.12 (SCL), U12.4 (SCL)
/SCL_3V3: R10.2, U6.3 (SCL1), U7.4 (SCK)
/SDA: R3.2, U1.27 (PC4), U6.5 (SDA2), U8.11 (SDA), U12.1 (A1), U12.2 (A0), U12.3 (SDA)
/SDA_3V3: R11.2, U6.4 (SDA1), U7.3 (SDI)
/TXD: J2.6, U1.31 (PD1)
/VBAT: C3.1, C7.1, C8.1, C10.1, C11.2, C39.2, C41.1, C44.1, D5.2 (A), F1.2, NT3.2, R27.2
/VSYS: C14.1, C25.2, C27.1, C34.1, C35.1, Q5.3 (D), Q7.3 (D), R16.2, TP6.1, U3.3 (VI), U8.1 (ACN)
GNDA: C1.2, C2.2, C4.2, C5.2, C6.2, C7.2, C8.2, C9.2, C10.2, C11.1, C13.2, C14.2, C15.2, C16.2, C17.2, C18.1, C19.2, C20.2, C23.1, C24.2, C27.2, C28.2, C29.2, C30.2, C31.2, C33.2, C38.2, C40.2, C41.2, C42.2, C45.2, J2.8, J2.10, MK1.2 (GND), MK1.3 (GND), NT1.2, R4.2, R9.2, R23.2, R26.2, RV1.3, RV3.3, TP2.1, U1.3 (GND), U1.5 (GND), U1.21 (GND), U2.4 (GND), U3.1 (GND), U4.1 (GND), U5.1 (GND), U6.1 (GND), U7.1 (GND), U7.5 (SDO), U7.7 (GND), U8.22 (AGND), U9.2 (GND), U10.2 (GND), U12.6 (GND)
GNDPWR: C3.2, C26.2, C34.2, C35.2, C36.2, C44.2, D6.2 (A2), J1.1, J3.1, NT1.1, Q6.2 (S), R7.2, R20.2, RV2.2, U8.13 (CMPIN), U8.29 (PGND)
unnamed: C12.2, R7.1
unnamed: D1.1 (A1), Q2.3 (D)
unnamed: D1.3 (A2), Q1.3 (D)
unnamed: D1.2 (K), R4.1
unnamed: D3.1 (K), D5.1 (K), R21.2
unnamed: D4.2 (A), U9.1 (OUT)
unnamed: D6.1 (A1), D7.2 (A), J3.2, R20.1
unnamed: D7.1 (K), F2.1
unnamed: F1.1, J1.2
unnamed: C37.1, MK1.4 (OUT)
unnamed: Q3.1 (G), R12.1
unnamed: C22.1, Q3.2 (S), Q4.2 (S), R14.1
unnamed: C24.1, C25.1, Q4.3 (D), R16.1, U8.2 (ACP)
unnamed: C21.2, C22.2, Q4.1 (G), R12.2, R13.1, TP11.1
unnamed: Q5.1 (G), U8.26 (HIDRV)
unnamed: C32.2, L3.1, Q5.2 (S), Q6.3 (D), U8.27 (PHASE)
unnamed: Q6.1 (G), U8.23 (LODRV)
unnamed: C5.1, U1.7 (XTAL1/PB6), X1.2
unnamed: C6.1, U1.8 (XTAL2/PB7), X1.1
unnamed: C23.2, R15.2, U6.7 (VREF2), U6.8 (EN)
unnamed: R8.2, R9.1, TP9.1, U8.6 (ACDET)
unnamed: R13.2, U8.4 (ACDRV)
unnamed: R19.1, TP12.1, U8.5 (ACOK)
unnamed: R17.2, U8.18 (BATDRV)
unnamed: R18.2, U8.17 (BATSRC)
unnamed: C32.1, U8.25 (BTST)
unnamed: R14.2, U8.3 (CMSRC)
unnamed: C26.1, U8.21 (ILIM), U8.24 (REGN)
unnamed: R28.2, U8.19 (SRN)
unnamed: R24.2, U8.20 (SRP)
unnamed: C30.1, R21.1, U8.28 (VCC)
unnamed: C29.1, RV1.2, U9.4 (Vin-)
unnamed: C37.2, R25.2, R26.1, TP7.1, U10.3 (Vin+)
unnamed: RV3.2, U10.4 (Vin-)
unnamed: R29.1, U12.8 (VIN_+)
unnamed: R30.2, U12.7 (VIN_-)

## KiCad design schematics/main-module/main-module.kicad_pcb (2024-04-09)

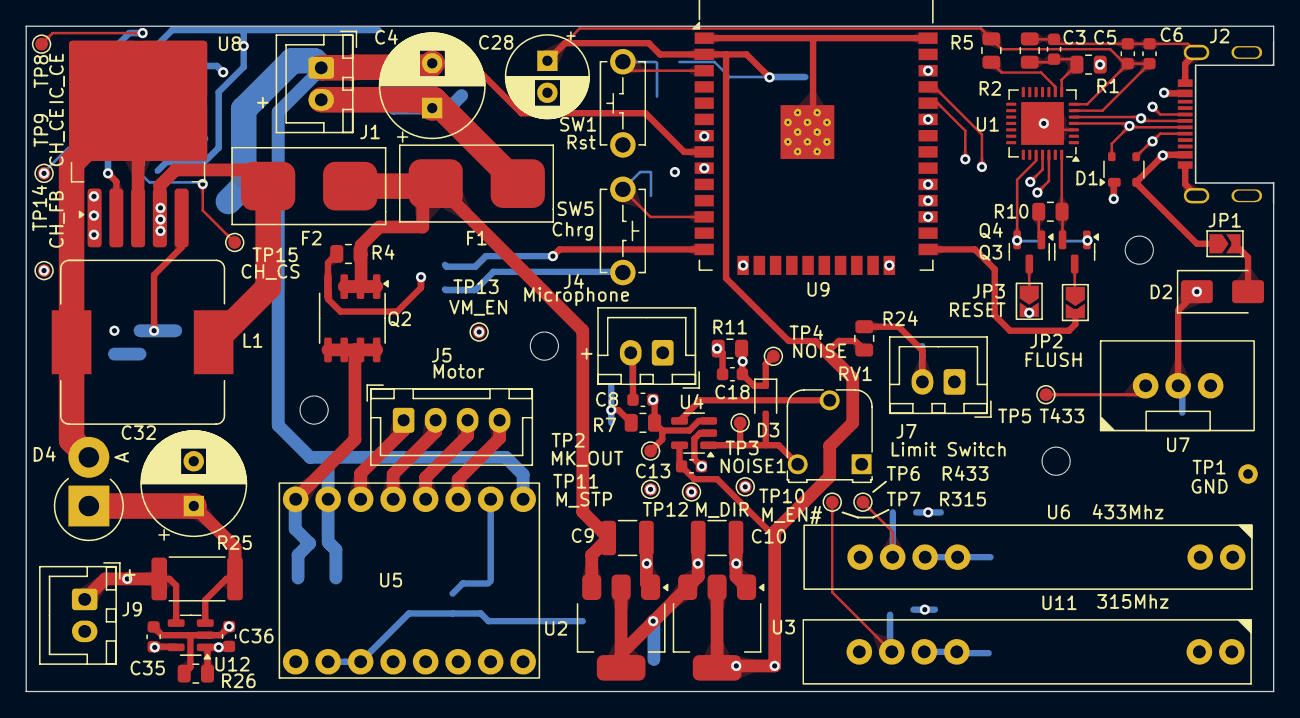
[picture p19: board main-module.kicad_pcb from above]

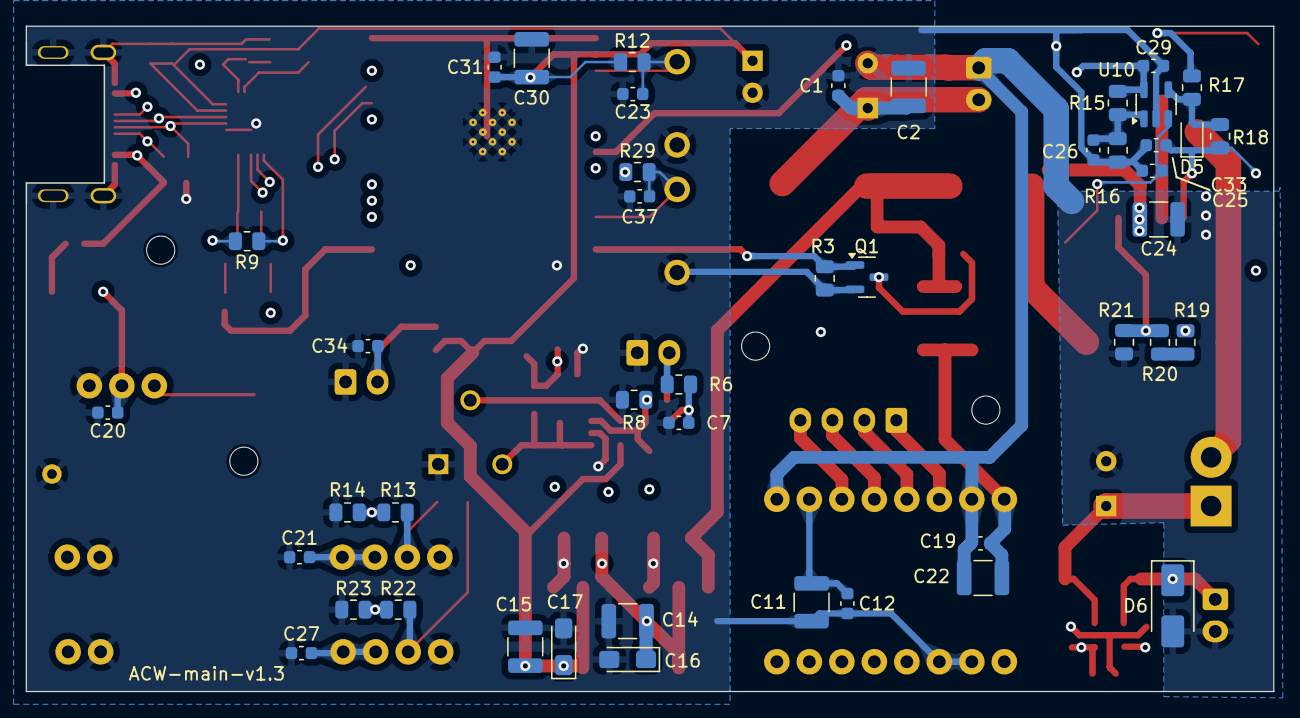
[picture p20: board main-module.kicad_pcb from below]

Board: 4 copper layers, 97.5 x 52.0 mm, 121 parts (45 on the bottom side), 55 nets.

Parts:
C1, C12, C19, C20, C21, C27, C31: 4.7 uF; C_0603_1608Metric
C2, C9, C10, C11, C14, C15, C22, C24, C30: 22 uF; C_1210_3225Metric
C3, C5, C6, C33: 10 uF; C_0603_1608Metric
C4: 1000 uF; CP_Radial_D8.0mm_P3.50mm
C7, C13, C29, C35: 100 nF; C_0603_1608Metric
C8: 47 nF; C_0603_1608Metric
C16, C17: 22 uF; CP_EIA-3216-10_Kemet-I_Pad1.58x1.35mm_HandSolder
C18: 1 uF; C_0603_1608Metric
C23, C34, C37: 330 nF; C_0603_1608Metric
C25, C26, C36: 10 nF; C_0603_1608Metric
C28: 100 uF; CP_Radial_D6.3mm_P2.50mm
C32: 220 uF@35V; CP_Radial_D8.0mm_P3.50mm
D1: SP0503BAHT; SOT-143
D2: US1M; D_SMA
D3, D5: BAV21WS; D_SOD-323F
D4: SR540; D_DO-201AD_P3.81mm_Vertical_AnodeUp
D6: SMAJ26A; D_SMA
F1: 6A; FuseHolder1808
F2: 3A; FuseHolder1808
H1, H2, H3, H4: MountingHole; MountingHole_2.2mm_M2
J1: Conn_01x02_Socket; JST_XH_B2B-XH-A_1x02_P2.50mm_Vertical
J2: USB_C_Receptacle_USB2.0; USB_C_P16_MIDMOUNT_1.6
J4: Microphone; JST_XH_B2B-XH-A_1x02_P2.50mm_Vertical
J5: Conn_01x04_Socket; JST_XH_B4B-XH-A_1x04_P2.50mm_Vertical
J7: Limit Switch; JST_XH_B2B-XH-A_1x02_P2.50mm_Vertical
J9: Charger port; JST_XH_B2B-XH-A_1x02_P2.50mm_Vertical
JP1: Charge from flusher; SolderJumper-2_P1.3mm_Open_TrianglePad1.0x1.5mm
JP2: FLUSH; SolderJumper-2_P1.3mm_Open_TrianglePad1.0x1.5mm
JP3: RESET; SolderJumper-2_P1.3mm_Open_TrianglePad1.0x1.5mm
L1: AMPLF1260, 4.7 uH; L_TaiTech_TMPC1265_13.5x12.5mm
NT1: AGND/PGND; NetTie-2_SMD_Pad2.0mm
Q1: IRLML0030; SOT-23
Q2: IRF7425PbF; SOIC-8_3.9x4.9mm_P1.27mm
Q3, Q4: BC847; SOT-23
R1, R13, R22: 22K; R_0805_2012Metric
R2, R14, R23: 47K; R_0805_2012Metric
R3, R6, R8, R9, R10, R11, R15, R20, R24, R29: 10K; R_0805_2012Metric
R4, R5, R12, R19, R21: 1K; R_0805_2012Metric
R7: 20K; R_0805_2012Metric
R16: 200; R_0805_2012Metric
R17: 620; R_0805_2012Metric
R18: 200K; R_0805_2012Metric
R25: 0,5; R_2512_6332Metric
R26: 100K; R_0805_2012Metric
RV1: RM065, 100K; Potentiometer_Runtron_RM-065_Vertical
SW1, SW5: KLS7-TS3601-5.0-180; SW_PUSH_P6.5_W3.5
TP1: GND; TestPoint_Plated_Hole_D1.0mm
TP2: MK_OUT; TestPoint_Pad_D1.0mm
TP3: NOISE1; TestPoint_Pad_D1.0mm
TP4: NOISE; TestPoint_Pad_D1.0mm
TP5: T433; TestPoint_Pad_D1.0mm
TP6: R433; TestPoint_Pad_D1.0mm
TP7: R315; TestPoint_Pad_D1.0mm
TP8: IC_CE; TestPoint_Pad_D1.0mm
TP9: CH_CE; TestPoint_Pad_D1.0mm
TP10: M_EN#; TestPoint_Pad_D1.0mm
TP11: M_STP; TestPoint_Pad_D1.0mm
TP12: M_DIR; TestPoint_Pad_D1.0mm
TP13: VM_EN; TestPoint_Pad_D1.0mm
TP14: CH_FB; TestPoint_Pad_D1.0mm
TP15: CH_CS; TestPoint_Pad_D1.0mm
U1: CP2102N-Axx-xQFN28; QFN-28-1EP_5x5mm_P0.5mm_EP3.35x3.35mm
U2: AMS1117-5.0; SOT-223-3_TabPin2
U3: AMS1117-3.3; SOT-223-3_TabPin2
U4: AD8541; SOT-23-5
U5: TMC2209_Module; TMC2209
U6: SRX882@433Mhz; SRX882_Vertical
U7: STX882@433Mhz; STX882_Vertical
U8: XL6009; TO-263-5_TabPin3
U9: ESP32-WROOM-32
U10: TL331; SOT-23-5
U11: SRX882@315Mhz; SRX882_Vertical
U12: INA169; SOT-23-5

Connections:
+3V3: C5.1, C6.1, C11.2, C12.1, C13.1, C15.2, C17.1, C28.1, C30.2, C31.1, R5.2, R12.1, R24.1, R29.1, U1.6 (VDD), U1.7 (VREGIN), U3.2 (VO), U4.5 (V+), U5.15 (VIO), U9.2 (VDD)
+5V: C7.1, C10.2, C14.2, C16.1, C20.1, C21.1, C27.1, C29.1, C35.1, D2.1 (K), R6.2, R7.2, R15.2, U2.2 (VO), U3.3 (VI), U6.3 (VCC), U6.4 (CS), U7.3 (VCC), U10.5 (V+), U11.3 (VCC), U11.4 (CS), U12.5 (V+)
+7.5V: C9.2, F1.2, F2.1, Q2.1 (S), Q2.2 (S), Q2.3 (S), R4.1, U2.3 (VI)
/7.5V_BEFORE_FUSE: C1.1, C2.1, C4.1, F1.1, J1.2
/+7.5V_CHARGER_AFTER_FUSE: C24.2, F2.2, L1.2, U8.4 (VIN)
/CHARGER_CURRENT_SENCE: C25.2, C36.2, R26.2, TP15.1, U10.3 (+), U12.1
/CHARGER_ENABLE: C33.2, D5.1 (K), R18.1, TP9.1, U8.2 (EN)
/CHARGER_FEEDBACK: R20.1, R21.2, TP14.1, U8.5 (FB)
/CHARGER_START_BUTTON: C37.1, R29.2, SW5.1, U9.12 (IO27)
/D+: D1.4 (K), J2.A6 (D+), J2.B6 (D+), U1.4 (D+)
/D-: D1.3 (K), J2.A7 (D-), J2.B7 (D-), U1.5 (D-)
/ESP32_ENABLE: C23.1, JP3.2 (B), R12.2, SW1.2, U9.3 (EN)
/ESP32_FLUSH: JP2.2 (B), U9.25 (IO0)
/FM_IN_5V_315: R22.2, TP7.1, U11.5 (DATA)
/FM_IN_5V_433: R13.2, TP6.1, U6.5 (DATA)
/FM_IN_315: R22.1, R23.2, U9.33 (IO21)
/FM_IN_433: R13.1, R14.2, U9.29 (IO5)
/FM_OUT_433: TP5.1, U7.2 (DATA), U9.36 (IO22)
/IC_CHARGER_ENABLE: R17.2, TP8.1, U9.8 (IO32)
/LIMIT_SWITCH: C34.1, J7.2, R24.2, U9.9 (IO33)
/M_DIR: TP12.1, U5.8 (DIR), U9.27 (IO16)
/M_ENABLE#: TP10.1, U5.1 (ENABLE#), U9.24 (IO2)
/M_STEP: TP11.1, U5.7 (STEP), U9.28 (IO17)
/NOISE: C18.1, D3.1 (K), R11.2, TP4.1, U9.7 (IO35)
/RXD_3V3: U1.26 (TXD), U9.34 (RXD0/IO3)
/TXD_3V3: U1.25 (RXD), U9.35 (TXD0/IO1)
/VM_ENABLE: Q1.1 (G), R3.1, TP13.1, U9.14 (IO12)
GNDA: C1.2, C2.2, C3.2, C4.2, C5.2, C6.2, C7.2, C9.1, C10.1, C11.1, C12.2, C13.2, C14.1, C15.1, C16.2, C17.2, C18.2, C20.2, C21.2, C23.2, C25.1, C26.1, C27.2, C28.2, C29.2, C30.1, C31.2, C33.1, C34.2, C35.2, C36.1, C37.2, D1.1 (A), J2.A1 (GND), J2.A12 (GND), J2.B1 (GND), J2.B12 (GND), J2.S1 (SHIELD), J4.1, J7.1, NT1.2, Q1.2 (S), R2.2, R3.2, R8.1, R11.1, R14.1, R16.1, R23.1, R26.1, RV1.1, SW1.1, SW5.2, TP1.1, U1.3 (GND), U1.29 (GND), U2.1 (GND), U3.1 (GND), U4.2 (GND), U5.2 (MS1), U5.3 (MS2), U6.2 (GND), U6.6 (GND), U7.4 (GND), U9.1 (GND), U9.15 (GND), U9.38 (GND), U9.39 (GND), U10.2 (V-), U11.2 (GND), U11.6 (GND), U12.2 (GND)
GNDPWR: C19.1, C22.1, C24.1, C32.2, D6.2 (A2), J1.1, J9.2, NT1.1, R21.1, U5.10 (GND), U5.16 (GND), U8.1 (GND)
unnamed: D2.2 (A), JP1.2 (B)
unnamed: D3.2 (A), RV1.3, TP3.1, U4.1 (OUT)
unnamed: D4.2 (A), L1.1, U8.3 (SW)
unnamed: C32.1, D4.1 (K), R19.2, R25.1, U12.3 (+)
unnamed: D5.2 (A), R17.1, R18.2, U10.4
unnamed: D6.1 (A1), J9.1, R25.2, U12.4 (-)
unnamed: C8.1, J4.2, R6.1
unnamed: J5.1, U5.11 (M1B)
unnamed: J5.2, U5.12 (M1A)
unnamed: J5.3, U5.13 (M2A)
unnamed: J5.4, U5.14 (M2B)
unnamed: JP2.1 (A), Q3.3 (C)
unnamed: JP3.1 (A), Q4.3 (C)
unnamed: Q1.3 (D), Q2.4 (G), R4.2
unnamed: Q3.1 (B), R9.2
unnamed: Q3.2 (E), R10.1, U1.28 (~DTR)
unnamed: Q4.1 (B), R10.2
unnamed: Q4.2 (E), R9.1, U1.24 (~RTS)
unnamed: R19.1, R20.2
unnamed: C3.1, R1.2, R2.1, U1.8 (VBUS)
unnamed: R5.1, U1.9 (~RST)
unnamed: C8.2, R7.1, R8.2, TP2.1, U4.3 (Vin+)
unnamed: RV1.2, U4.4 (Vin-)
unnamed: C26.2, R15.1, R16.2, U10.1 (-)
VBUS: D1.2 (K), J2.A4 (VBUS), J2.A9 (VBUS), J2.B4 (VBUS), J2.B9 (VBUS), JP1.1 (A), R1.1
VD: C19.2, C22.2, Q2.5 (D), Q2.6 (D), Q2.7 (D), Q2.8 (D), U5.9 (VM)

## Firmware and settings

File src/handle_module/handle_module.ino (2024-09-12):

#include "power_manager.h"
#include "led.h"
#include "user_input.h"
#include "fm_receiver.h"
#include "fm_sender.h"
#include "controller.h"
#include "fm_decoder.h"
//#include "power_manager_monitor.h"

void setup() {
  Serial.begin(9600);

  Serial.println("Starting");

//  power_manager_monitor_process();

  led_init();

  power_manager_init();

  controller_init();
  user_input_init();
  fm_sender_init();
  fm_receiver_init();

  Serial.println("Firmware initialized");
}

void loop() {
  fm_decoder_on_main_loop();
  controller_on_main_loop();
  power_manager_on_main_loop();
  fm_sender_on_main_loop();
  led_on_main_loop();
}

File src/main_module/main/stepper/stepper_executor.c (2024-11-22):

#include "stepper_executor.h"

#include "../controller/controller.h"

#include "stepper_one_step.h"
#include "../log/log.h"
#include "../common/delay_timer.h"
#include "../common/nvs_rw.h"

#include "driver/gpio.h"
#include "freertos/FreeRTOS.h"
#include "freertos/task.h"
#include "math.h"

#define STEPPER_COMMAND_TASK_STACK_SIZE 2048

// exec commmand:
// 0...100 - open to this percent
// > 100 - special codes
#define STEPPER_EXEC_CMD__MAX_MOVETO 100
#define STEPPER_EXEC_CMD__CALIBRATE  150
#define STEPPER_EXEC_CMD__IDLE       200
#define STEPPER_EXEC_CMD__CANCEL     201

#define STEPPER_MOTOR_OFF_DELAY_MILLIS  (60 * 1000)
#define STEPPER_EXEC_CURRENT_POSITION_UNKNOWN  0xFFFFFFFF

#define STEPPER_EXEC_REPORT_POSITION_MILLIS (1000)

#define STEPPER_EXEC_CORRECT_POSITION_TIMEOUT  1000

#define STEPPER_NVS_FULL_OPEN_STEPS "stp_full_open"
#define STEPPER_DEFAULT_FULL_OPEN_STEPS 1000

volatile uint8_t stepper_exec_command = STEPPER_EXEC_CMD__IDLE;
volatile bool stepper_executor_is_in_error_now = false;

t_endstops * endstops;
t_delay_timer * stepper_exec_stop_timer = NULL;
t_delay_timer * stepper_exec_report_position = NULL;
uint32_t stepper_exec_current_position = STEPPER_EXEC_CURRENT_POSITION_UNKNOWN;
uint32_t stepper_exec_max_position = STEPPER_EXEC_CURRENT_POSITION_UNKNOWN;
bool stepper_exec_unlock_on_endpos = true;

static void stepper_executor_on_execute_command_task(void*);

void stepper_executor_do_calibrate(uint8_t);
void stepper_executor_do_locate_position(uint8_t, bool);
void stepper_executor_do_moveto(uint8_t);

void stepper_executor_motor_on() {
	if (gpio_get_level(CONFIG_PIN_STEPPER_POWER_ON) == 0) {
		gpio_set_level(CONFIG_PIN_STEPPER_POWER_ON, 1);
		vTaskDelay(10 / portTICK_PERIOD_MS);
		gpio_set_level(CONFIG_PIN_STEPPER_ENABLE, 0);
		vTaskDelay(10 / portTICK_PERIOD_MS);
	}
}

void stepper_executor_motor_off() {
	gpio_set_level(CONFIG_PIN_STEPPER_ENABLE, 1);
	gpio_set_level(CONFIG_PIN_STEPPER_POWER_ON, 0);

	controller_on_stepper_position_updated(0xFF);
}

bool stepper_executor_is_motor_on() {
	return gpio_get_level(CONFIG_PIN_STEPPER_POWER_ON) == 1;
}

void stepper_executor_init(t_endstops * _endstops) {
	endstops = _endstops;

	gpio_config_t chargerEnableConfig = {
		.intr_type = GPIO_INTR_DISABLE,
	    .mode = GPIO_MODE_INPUT_OUTPUT,
		.pin_bit_mask = BIT64(CONFIG_PIN_STEPPER_ENABLE) |
		                BIT64(CONFIG_PIN_STEPPER_POWER_ON),
		.pull_down_en = GPIO_PULLDOWN_DISABLE,
		.pull_up_en = GPIO_PULLUP_DISABLE,
	};

	esp_err_t res = gpio_config(&chargerEnableConfig);
	if (res) {
		_ESP_LOGE(LOG_STEPPER_EXEC, "gpio_config error: %d", res);
		return;
	}

	stepper_one_step_init();

	stepper_exec_stop_timer = delay_timer_allocate(STEPPER_MOTOR_OFF_DELAY_MILLIS);
	stepper_exec_report_position = delay_timer_allocate(STEPPER_EXEC_REPORT_POSITION_MILLIS);

	_ESP_LOGI(LOG_STEPPER_EXEC, "Reading NVS");

	stepper_exec_max_position = nvs_read_32t(STEPPER_NVS_FULL_OPEN_STEPS, STEPPER_DEFAULT_FULL_OPEN_STEPS);
	_ESP_LOGI(LOG_STEPPER_EXEC, "Full-open-steps value : %li", stepper_exec_max_position);

	xTaskCreate(stepper_executor_on_execute_command_task, "stepper on execute command task", STEPPER_COMMAND_TASK_STACK_SIZE, NULL, 10, NULL);
}

static void stepper_executor_on_execute_command_task(void*) {
	_ESP_LOGI(LOG_STEPPER_EXEC, "Stepper execution task started");

	while(true) {
		if (stepper_executor_is_in_error_now) {
			if (stepper_exec_command != STEPPER_EXEC_CMD__IDLE) {
				controller_on_status(CONTROLLER_STATUS_ERROR_RAISED);
				stepper_exec_command = STEPPER_EXEC_CMD__IDLE;
			}

			if (stepper_exec_current_position != STEPPER_EXEC_CURRENT_POSITION_UNKNOWN) {
				stepper_exec_current_position = STEPPER_EXEC_CURRENT_POSITION_UNKNOWN;
			}

			if (stepper_executor_is_motor_on()) {
				stepper_executor_motor_off();
			}

			vTaskDelay(10 / portTICK_PERIOD_MS);
			continue;
		}

		if (stepper_exec_command == STEPPER_EXEC_CMD__IDLE) {
			if (stepper_exec_current_position != STEPPER_EXEC_CURRENT_POSITION_UNKNOWN) {
				if (stepper_exec_max_position != STEPPER_EXEC_CURRENT_POSITION_UNKNOWN) {
					if (stepper_exec_unlock_on_endpos &&
						   (stepper_exec_current_position == stepper_exec_max_position ||
							stepper_exec_current_position == 0)) {
						if (delay_timer_start_or_check(stepper_exec_stop_timer)) {
							stepper_exec_current_position = STEPPER_EXEC_CURRENT_POSITION_UNKNOWN;
							stepper_executor_motor_off();
						}
					}
				}

				if (!endstops->is_stepper_allowed()) {
					stepper_exec_current_position = STEPPER_EXEC_CURRENT_POSITION_UNKNOWN;
					stepper_executor_motor_off();
				}
			}

			vTaskDelay(10 / portTICK_PERIOD_MS);

			continue;
		}

		delay_timer_stop(stepper_exec_stop_timer);

		if (stepper_exec_command == STEPPER_EXEC_CMD__CANCEL) {
			_ESP_LOGW(LOG_STEPPER_EXEC, "Stepper execution cancelled");

			controller_on_status(
					stepper_executor_is_in_error_now ?
							CONTROLLER_STATUS_ERROR_RAISED :
							CONTROLLER_STATUS_TASK_CANCELLED);

			stepper_exec_command = STEPPER_EXEC_CMD__IDLE;

			if (stepper_exec_max_position == STEPPER_EXEC_CURRENT_POSITION_UNKNOWN) {
				stepper_exec_current_position = STEPPER_EXEC_CURRENT_POSITION_UNKNOWN;
			}

			if (stepper_exec_current_position == STEPPER_EXEC_CURRENT_POSITION_UNKNOWN) {
				stepper_executor_motor_off();
			}

			continue;
		}

		if (!endstops->is_stepper_allowed()) {
			_ESP_LOGW(LOG_STEPPER_EXEC, "Stepper execution not allowed, check limit switch");

			controller_on_status(CONTROLLER_STATUS_WINDOW_LOCK_OPENED);

			stepper_executor_motor_off();
			stepper_exec_current_position = STEPPER_EXEC_CURRENT_POSITION_UNKNOWN;

			stepper_exec_command = STEPPER_EXEC_CMD__IDLE;

			continue;
		}

		stepper_executor_motor_on();

		uint8_t currentcommand = stepper_exec_command;

		if (currentcommand == STEPPER_EXEC_CMD__CALIBRATE) {
			stepper_executor_do_calibrate(currentcommand);
		} else if (currentcommand <= STEPPER_EXEC_CMD__MAX_MOVETO) {
			stepper_executor_do_moveto(currentcommand);
		}

		if (stepper_exec_command == currentcommand) {
			stepper_exec_command = STEPPER_EXEC_CMD__IDLE;
		}
	}
}

void stepper_executor_calibrate() {
	stepper_executor_is_in_error_now = false; // calibration resets error flag
	stepper_exec_command = STEPPER_EXEC_CMD__CALIBRATE;
}

bool stepper_executor_is_now_executing_move_to(uint8_t percent) {
	if (stepper_executor_is_in_error_now) {
		return false;
	}

	return stepper_exec_command == percent;
}

void stepper_executor_moveto(uint8_t percent) {
	if (!stepper_executor_is_in_error_now) {
		stepper_exec_command = percent;
	} else {
		_ESP_LOGW(LOG_STEPPER_EXEC, "Command 'move to percent %d%%' skipped - we in error now.", percent);
		controller_on_status(CONTROLLER_STATUS_ERROR_RAISED);
	}
}
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

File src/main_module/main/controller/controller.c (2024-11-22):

#include "controller.h"

#include "controller_mqtt.h"
#include "../fm/fm_command_address_def.h"
#include "../fm/fm_command_defs.h"
#include "../fm/fm_sender.h"
#include "../log/log.h"
#include "../stepper/stepper_init.h"
#include "../charger/charger_init.h"
#include "../common/nvs_rw.h"
#include "stdbool.h"
#include <string.h>

#include "controller_args_def.h"

#include "freertos/FreeRTOS.h"
#include "freertos/task.h"

// This codes used by my remote control unit
// Change them to your codes.
// You can just press buttons and check log messages
#define CONTROLLER_PDU1_ARG_BUTTON1   0x68
#define CONTROLLER_PDU1_ARG_BUTTON2   0x64
#define CONTROLLER_PDU1_ARG_BUTTON3   0x62
#define CONTROLLER_PDU1_ARG_BUTTON4   0x61
#define CONTROLLER_PDU2_ARG_BUTTON1   0xA8
#define CONTROLLER_PDU2_ARG_BUTTON2   0xA4
#define CONTROLLER_PDU2_ARG_BUTTON3   0xA2
#define CONTROLLER_PDU2_ARG_BUTTON4   0xA1

#define CONTROLLER_BAT_STATUS_V_OFFSET 450

#define CONTROLLER_MQTT_ASYNC_MESSAGE__ERROR     1
#define CONTROLLER_MQTT_ASYNC_MESSAGE__POSITION  2
#define CONTROLLER_MQTT_ASYNC_MESSAGE__UNLOCK_EN 3

#define CONTROLLER_ASYNC_MQTT_TASK_STACK_SIZE 4096

#define CONTROLLER_LIGHT_OPEN_PERCENT 10
#define CONTROLLER_LIGHT_OPEN_PERCENT_CONFIG "cntrl_lopc"

static volatile uint8_t controller_light_open_percent = CONTROLLER_LIGHT_OPEN_PERCENT;
static volatile uint8_t controller_fm_pdu_enabled = true;

QueueHandle_t controller_mqtt_async_message_queue;

static void controller_mqtt_async_message_task(void*);

void controller_process_pdu1_command(uint16_t freq, uint8_t arg) {
	_ESP_LOGI(LOG_CONTROLLER, "PDU1 command: arg=%02X on freq %d", arg, freq);

	if (!controller_fm_pdu_enabled) {
		_ESP_LOGW(LOG_CONTROLLER, "PDU commands disabled.");
		return;
	}

	switch (arg) {
		case CONTROLLER_PDU1_ARG_BUTTON1:
			stepper_move_to(0);
			break;
		case CONTROLLER_PDU1_ARG_BUTTON2:
			stepper_move_to(controller_light_open_percent);
			break;
		case CONTROLLER_PDU1_ARG_BUTTON3:
			stepper_move_to(100);
			break;
		case CONTROLLER_PDU1_ARG_BUTTON4:
			stepper_cancel();
			break;
	}
}

void controller_process_pdu2_command(uint16_t freq, uint8_t arg) {
	_ESP_LOGI(LOG_CONTROLLER, "PDU2 command: arg=%02X on freq %d", arg, freq);

	if (!controller_fm_pdu_enabled) {
		_ESP_LOGW(LOG_CONTROLLER, "PDU commands disabled.");
		return;
	}

	switch (arg) {
		case CONTROLLER_PDU2_ARG_BUTTON1:
			stepper_move_to(0);
			break;
		case CONTROLLER_PDU2_ARG_BUTTON2:
			stepper_move_to(controller_light_open_percent);
			break;
		case CONTROLLER_PDU2_ARG_BUTTON3:
			stepper_move_to(100);
			break;
		case CONTROLLER_PDU2_ARG_BUTTON4:
			stepper_cancel();
			break;
	}
}
void controller_process_hm_command(uint16_t freq, uint8_t arg) {
	_ESP_LOGI(LOG_CONTROLLER, "HM command: arg=%02X on freq %d", arg, freq);

	switch (arg) {
		case CONTROLLER_HM_FULL_OPEN:
			if (stepper_is_now_executing_move_to(100)) {
				stepper_cancel();
			} else {
				stepper_move_to(100);
			}
			break;
		case CONTROLLER_HM_FULL_CLOSE:
			if (stepper_is_now_executing_move_to(0)) {
				stepper_cancel();
			} else {
				stepper_move_to(0);
			}
			break;
		case CONTROLLER_HM_CALIBRATE:
			stepper_calibrate();
			break;
		case CONTROLLER_HM_CANCEL_ERROR:
			stepper_cancel_error();
			break;
		default:
			ESP_LOGW(LOG_CONTROLLER, "HM command : unknown arg %02X", arg);
			break;
	}
}

void controller_process_hm_charge_status(bool charge_in_progress) {
	if (charge_in_progress) {
		charger_confirm_in_progress();
	} else {
		charger_stop();
	}
}

void controller_process_om_charge_status(bool charge_in_progress) {
	if (charge_in_progress) {
		charger_confirm_in_progress();
	} else {
		charger_stop();
	}
}

void controller_process_hmom_bat_status(bool hm, uint8_t _voltage, uint8_t _current) {
	uint16_t v = ((uint16_t)_voltage + CONTROLLER_BAT_STATUS_V_OFFSET) * 10;
	bool charge_in_progress = !(_current & 0b10000000);
	_current = _current & 0b01111111;
	uint16_t i = (uint16_t) _current * (uint16_t) 10;

	controller_mqtt_process_bat_status(hm, v, i, charge_in_progress);
}

void controller_process_command(uint16_t freq, const t_fm_command * command) {
	const uint8_t * args = command->args;

	switch (command->address) {
	case FM_COMMAND_ADDRESS__PDU1:
		controller_process_pdu1_command(freq, args[0]);
		break;

	case FM_COMMAND_ADDRESS__PDU2:
		controller_process_pdu2_command(freq, args[0]);
		break;

	case FM_COMMAND_ADDRESS__MM_STEPPER_STATUS:
		_ESP_LOGI(LOG_CONTROLLER, "Received self message with arg = %02X on freq %d", args[0], freq);
		// ignore this address - I receive myself commands
		break;

	case FM_COMMAND_ADDRESS__OM_CHARGE_STATUS:
		controller_process_om_charge_status(args[0]);
		break;
	case FM_COMMAND_ADDRESS__OM_ALARM:
		controller_mqtt_process_om_noise_alarm(args[0]);
		break;
	case FM_COMMAND_ADDRESS__OM_AIR_STATUS:
		controller_mqtt_process_om_air_data(args[0] - 100,
				                            args[1],
							     		    (args[2] << 16) + (args[3] << 8) + args[4]);
		break;
	case FM_COMMAND_ADDRESS__OM_NOISE_DATA:
		controller_mqtt_process_om_noise_data(args[0], args[1],
									          args[2], args[3],
									          args[4], args[5],
									          args[6], args[7],
									          args[8], args[9]);
		break;

	case FM_COMMAND_ADDRESS__HM_COMMAND:
		controller_process_hm_command(freq, args[0]);
		break;
	case FM_COMMAND_ADDRESS__HM_CHARGE_STATUS:
		controller_process_hm_charge_status(args[0]);
		break;
	case FM_COMMAND_ADDRESS__HM_BAT_STATUS:
		controller_process_hmom_bat_status(true, args[0], args[1]);
		break;
	default:
		_ESP_LOGW(LOG_CONTROLLER, "Unknown address = %04X (arg0 == %02X)", command->address, args[0]);
		break;
	}
}

void controller_on_status(uint8_t status) {
	t_fm_command cmd;
	memset(&cmd, 0, sizeof(t_fm_command));
	cmd.address = FM_COMMAND_ADDRESS__MM_STEPPER_STATUS;
	cmd.args[0] = status;
	cmd.args_size = 1;

	fm_sender_send(&cmd);

	if (status == CONTROLLER_STATUS_ERROR_RAISED || status == CONTROLLER_STATUS_ERROR_CANCELLED) {
		uint16_t x = (status << 8) + CONTROLLER_MQTT_ASYNC_MESSAGE__ERROR;
		xQueueSend(controller_mqtt_async_message_queue, &x, 0);
	}
}

void controller_on_stepper_position_updated(uint8_t percent) {
	uint16_t x = (percent << 8) + CONTROLLER_MQTT_ASYNC_MESSAGE__POSITION;
	xQueueSend(controller_mqtt_async_message_queue, &x, 0);
}

void controller_on_executor_allow_unlock(bool allowed) {
	uint16_t x = (allowed << 8) + CONTROLLER_MQTT_ASYNC_MESSAGE__UNLOCK_EN;
	xQueueSend(controller_mqtt_async_message_queue, &x, 0);
}
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

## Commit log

2021-07-27 Continue working under schematics
    [full_schema.sch]
2021-07-27 Added driver for servo FS5103B
    [partitions.csv]
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2021-08-03 1. working under schematics. 2. ESP32 firmware writen but not tested yet. 3. I conntected to ATMega controller and uploaded test firmware to it
    [full_schema.sch]
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2021-08-13 SGP30 Module works now
    [full_schema.sch]
2021-08-17 actualized schematics of outdoor noise sensor module
    [full_schema.sch]
2021-08-17 actualized some nominals in schematics
    [full_schema.sch]
2021-09-26 Changed Noise sensor schematics. Removed MSGEQ7 chip (replaced with program FFT). I cant find any live. Changed Volume Amplifier from transistors to chio.
    [full_schema.sch]
2021-09-26 Noise sensor works
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2021-10-30 changed schematics. Removed 433MHZ transmitter. Outdoor module will transfer data using ESP32
    [full_schema.sch]
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2021-10-30 Estabilished connection between AVR and ESP32. ESP32 ready to read data from AVR and send it into MQTT
    [full_schema.sch]
2021-10-31 Change noise sensor schema
    [full_schema.sch]
2021-11-04 changed microcontroller to ATMEGA328P to reduce device size
    [full_schema.sch]
2021-11-04 Added TX and RX links from USBASP to ATMEGA
    [full_schema.sch]
2021-11-04 Firmware and ATMega connection are synchronized. USBasp works successfully
    [full_schema.sch]
2021-11-04 full schema on atmega328 tested and worked
    [full_schema.sch]
2021-11-05 Start boards preparing - actualized new element dimentions
    [full_schema.sch]
2021-11-05 Touch sensor are unstable. I made a decision to replace it by normally-open buttons
    [full_schema.sch]
2021-11-06 Added button borders and nominals
    [full_schema.sch]
2021-11-07 Start working under first border
    [full_schema.sch, indoor_nearhandle_module.brd, indoor_nearhandle_module.sch]
2021-11-07 Board redesigned to reduce it width
    [indoor_nearhandle_module.brd]
2021-11-07 Indoor board - ready
    [indoor_nearhandle_module.brd, indoor_nearhandle_module.sch]
2021-11-07 Indoor board - added ground polygon
    [indoor_nearhandle_module.brd]
2021-11-07 Start working under second border
    [indoor_nearhandle_module.brd, indoor_servo_module.brd, indoor_servo_module.sch]
2021-11-08 Servo module ready, but i will change connectors
    [indoor_servo_module.brd]
2021-11-08 Servo module - added holes
    [indoor_servo_module.brd]
2021-11-08 Added board for outdoor module
    [outdoor_module.brd, outdoor_module.sch]
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2021-11-08 Fixed issue in one border - all supply lines now connected to capacity only. And from filter capacity power goes to another elements.
    [indoor_servo_module.brd]
2021-11-08 Increased supply line size to servo
    [indoor_servo_module.brd]
2021-11-08 Outdoor module board size reduced
    [indoor_nearhandle_module.brd, indoor_servo_module.brd, indoor_servo_module.sch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]
2021-11-09 Start preparing to order boards. Checked all labels
    [indoor_nearhandle_module.brd, indoor_servo_module.brd, outdoor_module.brd]
2021-11-09 Boards checked and ready to order
    [indoor_nearhandle_module.brd, indoor_servo_module.brd, indoor_servo_module.sch]
2021-11-09 Holes moved away from board border
    [indoor_nearhandle_module.brd, indoor_servo_module.brd, outdoor_module.brd]
2021-12-17 Touchpad driver replaced by buttons driver.
    [controller.c]
2021-12-17 hear handle module & indoor servo module assembled and checked
    [full_schema.sch]
2021-12-17 fixed error in outdoor board and schema
    [outdoor_module.brd, outdoor_module.sch]
2021-12-17 actualized voltage regulator nominal
    [outdoor_module.brd, outdoor_module.sch]
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2021-12-19 3D models for box
    [indoor-hearhandle-top.FCStd, servo-handle-1.FCStd, servo-top.FCStd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]
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2021-12-23 Continue working under 3D models
    [servo-handle-1.FCStd, servo-handle-2.FCStd, servo-handle-2.stl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]
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2021-12-25 Fixed errors in 3D model connector betwween servo handler and window
    [servo-handle-2.FCStd, servo-handle-2.stl, servo-handle-3.FCStd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]
2021-12-29 changes in 3D models
    [closed-window-lock-plate.FCStd, closed-window-lock-plate.stl, closed-window-lock-top-angle.stl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]
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2021-12-30 fixed error in servo box
    [servo-bottom.FCStd, servo-bottom.stl, servo-top.FCStd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]
2021-12-31 Ok, I think I finished with indoor 3D models. Outdoor box printing reuqired.
    [outdoor-bottom.FCStd, servo-bottom-cork.stl, servo-bottom.FCStd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]
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2023-09-11 Creating schematics and boards
    [cakc.ods, handle-module.csv, handle-module.kicad_pcb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]
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2023-09-12 changes in second board
    [outdoor-module.kicad_pcb, outdoor-module.kicad_sch]
2023-11-02 Project prepared to order
    [cakc.ods, coil-bracket.stl, coil-buttom.stl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]
2023-11-29 first version of main-module firmware. not tested yet.
    [handle-module.csv, handle-module.kicad_sch, main-module.csv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]
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2023-12-01 WIFI & NQTT integration
    [partitions.csv]
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2023-12-05 1. start working under handle module; 2. rewrite stepper driver
    [handle-module.kicad_pcb, main-module.kicad_pcb, main-module.kicad_sch]
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2023-12-11 1. first 3D models, 2. charger works
    [cakc.ods, handle-module.kicad_sch, mechanics-limiters.stl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]
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2023-12-13 Working under 3d models
    [mechanics-limiters.stl, mechanics-plate.stl, mechanics-servo-holder.stl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]
2023-12-14 1. Fixed schema - limit switch connection moved to ADC pin
    [main-module-B_Cu.gbr, main-module-B_Mask.gbr, main-module-B_Paste.gbr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]
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2024-01-07 Adjust models to my window
    [mechanics-limit-switch-cup.stl, mechanics-limit-switch-lock.stl, mechanics-limit-switch.stl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]
2024-04-09 1. board: added protection against high noise in case of endstop is broken. 2. board: added step-up 7.5V -> 15V for charger. 3. firmware - added support for noise protection and some changes in stepp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
    [cakc.ods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]
2024-04-09 added deglich in noise protection.
    [stepper_init.c]
2024-04-10 Firmware uploaded and tested on the board (without noise sensor at this moment)
    [stepper_executor.c]
2024-05-11 another iteration for outdorr and handle modules
    [cakc.ods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]
2024-05-14 removed blind vias - it's production is too expensive
    [handle-module-B_Cu.gbr, handle-module-B_Mask.gbr, handle-module-B_Paste.gbr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]
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2024-07-25 noise alarm changes after hardware test
    [cakc.ods, main-module.kicad_sch]
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2024-08-29 prepare to change ADC working mode to continuus
    [cakc.ods, handle-module.kicad_sch]
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2024-09-12 i found problems with 315MHZ freq (some transmitter blocks air near me). So I added another remote control and I will create box for it
    [main-module.kicad_sch, mechanics-v2-servo-holder-v2.stl]
2024-09-16 Fixes in models
    [mechanics-v2-microphone-air-ring.stl, mechanics-v2-pdu2pdu-box-up.stl, mechanics-v2-pdu2pdu2-box-down.stl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]
2024-09-23 adding auto-hide mechanics allows to remove lock mechanizm from window way in unlocked state
    [mechanics-v2-rubberrubber-bearing-holder.stl, mechanics-v2-rubberrubber-tensioner.stl, mechanics-v2-servo_platemicrophone-air-border.stl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]
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2024-10-03 drill template fixed
    [mechanics-v2-servo_platedebug-wall-support.stl]
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2024-10-14 1. publish initial state after startup; 2. changes in 3D model after testing
    [mechanics-v2-window-clampwindow-clamp-1-r-sw-hand-left.stl, mechanics-v2-window-clampwindow-limit-sw-holder.stl]
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2024-11-01 fix PDU buttons mapping
    [controller.c]
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
